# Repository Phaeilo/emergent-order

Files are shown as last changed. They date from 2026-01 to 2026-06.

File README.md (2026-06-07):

# /dev/emergent_order

An experiment in chaos and structure, presented at 39c3 (39th Chaos Communication Congress).

A 1×1×1m LED cube art installation filled with 1200 individually addressable WS2812B LEDs, creating a volumetric 3D display.

Assembled LED cube

## Overview

This repository contains most materials involved in creating the LED cube installation: software, firmware, animations, 3D mechanical parts, PCB designs, calibration tools, and documentation. The aim is to document the complete structure of the cube and make relevant tools and designs available to others who want to build their own version, learn from the project, create derivative works, or apply these concepts in entirely new ways.

## Project Structure

This repository contains the following subdirectories:

**Note:** Some directories mentioned below may not yet be available in the repository. We are actively uploading the remaining materials and expect to have everything published within the next few days.

### Hardware & Electronics

- **`controller_pcb/`** - KiCad project for a high-performance 8-channel WS2812 controller based on the Raspberry Pi Pico. Features include USB streaming mode, standalone operation with built-in test patterns, SD card playback, comprehensive monitoring (voltage, current, temperature), and per-channel smart fuse protection (3.7A). Supports up to 200 LEDs per channel at 60Hz. See [controller_pcb/README.md](controller_pcb/README.md) for complete specifications.

- **`pico_firmware/`** - C firmware for the Raspberry Pi Pico that drives 8 independent WS2812B channels via PIO hardware. Features gamma correction, automatic current limiting, hardware monitoring (temperature, current, voltage), channel fault detection, and built-in test patterns including a ternary-encoded calibration pattern for camera-based position recovery. See [pico_firmware/README.md](pico_firmware/README.md) for protocol specification and development setup.

- **`mechanical/`** - 3D printable parts (base, corners, combs, controller mounts) and carbon fiber tube specifications for building the physical cube structure. See [mechanical/README.md](mechanical/README.md) for details.

### Software & Control

- **`showrunner/`** - Node.js service that plays LED animations on the cube, streaming frames at 30-60 FPS over serial to the Pico firmware. Supports hot-swappable animations and WebSocket interface for live streaming. See [showrunner/README.md](showrunner/README.md) for details.

- **`animations/`** - JavaScript animation scripts that generate LED patterns using 3D math (SDF primitives, planes, spheres, fire effects, etc.). See [animations/README.md](animations/README.md) for examples and animation format.

- **`animation_designer/`** - Web-based tool for designing and previewing animations before deploying them to the cube. See [animation_designer/README.md](animation_designer/README.md) for usage instructions.

### Calibration & Utilities

- **`calibration/`** - Tools for recovering 3D LED positions from video captures of the cube. Includes video frame extraction, LED detection with ternary color-coded identification, and multi-camera 3D triangulation with bundle adjustment. Features both Python CLI tools and a web-based detector with real-time visualization. See [calibration/README.md](calibration/README.md) for complete workflow and encoding scheme documentation.

- **`ws2serial/`** - Python utility for testing and interfacing with WS2812 LED strips over USB serial during development. Provides a WebSocket-to-serial adapter allowing the animation designer web tool to stream pixel data over the network to the Pico controller. See [ws2serial/README.md](ws2serial/README.md) for details.

- **`testdevice/`** - MicroPython code for ESP32-C3 to quickly test single LED strings during installation and teardown. See [testdevice/README.md](testdevice/README.md) for details.

### Prototypes

- **`minikube/`** - Smaller ~20×20×20cm prototype cube with MicroPython firmware and mechanical designs for ESP32-C3. Also includes a dodecahedron variant that reuses the same stick parts. See [minikube/README.md](minikube/README.md) for details.

## Technical Specifications

- **Physical size:** 1×1×1 meter cube
- **LEDs:** 1200 individually addressable WS2812B LEDs
- **Structure:** Carbon fiber tubes (20×18mm) with 3D printed corner connectors
- **Controller:** Raspberry Pi Pico-based 8-channel controller (can be driven by Raspberry Pi 3 or run standalone)
- **Power:** Custom 4-layer PCB with 8-channel power distribution, smart fuse protection (3.7A per channel), and comprehensive monitoring
- **Software:** Node.js showrunner + JavaScript animation framework (USB streaming), or standalone test patterns
- **Communication:** USB serial (Pi 3 → Pico), PIO-based WS2812B output, WebSocket interface for live animation streaming

## Development Approach

Most of the code in this project was synthesized ("vibe coded") using various Anthropic Claude models. The goal was to rapidly prototype and get something working, so the code may not be well understood in all places or may contain bugs. However, key decisions about architecture, algorithms and artistic content were provided by humans, just not manually implemented line-by-line.

## Related Works

Others have explored similar concepts in volumetric LED displays and spatial calibration:

- **Matt Parker's Christmas Tree (2020):** Matt Parker from the YouTube channel "Stand-up Maths" set up his Christmas tree with 500 LED lights in December 2020 and calculated their positions in 3D space. His well-made and educational video documenting the process: [I wired my tree with 500 LED lights and calculated their 3D coordinates.](https://www.youtube.com/watch?v=TvlpIojusBE)

- **Birk Schmithuesen's SpeculativeAI Series (2019-2022):** Artist Birk Schmithuesen created a sphere installation filled with 160 meters of LED strips comprising 9600 pixels. Through calibration work by Felix Bonowski, volumetric content was rendered on this sphere. The project is extensively documented at [birkschmithuesen.com/_speculativeAI](https://www.birkschmithuesen.com/_speculativeAI)

## License

See the license files in individual directories or license text in source files.

In general:
- **Code/Software:** MIT License
- **3D Models:** CC-BY 4.0
- **PCB Designs:** CERN-OHL-W (CERN Open Hardware License - Weakly Reciprocal)

## Contributing

This project was created for 39c3. Feel free to fork, modify, and create your own versions. If you build something based on this work, we'd love to hear about it!

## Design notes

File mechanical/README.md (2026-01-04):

# Mechanical Parts for LED Cube

This directory contains all the 3D models and specifications for building the physical structure of the 1×1×1m LED cube.

## Overview

The cube structure consists of:
- **Carbon fiber tubes** forming the main frame (12 edges of the cube)
- **3D printed connectors** to join the tubes at corners and base
- **3D printed cable management** combs to route LED wires
- **MDF base** housing all electronics
- **Controller mounting hardware**

## Bill of Materials

### Structural Components

#### Carbon Fiber Tubes

Ordered from "CARBON TIME" store on AliExpress:
- **Store:** [CARBON TIME](https://de.aliexpress.com/store/911756291)
- **Product:** [20mm Carbon Fiber Tubes](https://de.aliexpress.com/item/1005002337416341.html)

**Quantities needed:**
- 9× tubes 20×18×1000mm (outer × inner × length)
- 3× tubes 20×16×1000mm (for bottom connections to base)
  - Note: 20×18mm can be used for everything if you prefer consistency

**Finish:** Twill matte

#### LED Strings

**Product:** WS2812B addressable LED string ([AliExpress link](https://de.aliexpress.com/item/1005001915144430.html))

**Specifications:**
- 20m string with 10 LEDs per meter (200 LEDs total per string)
- 6 strings required for the installation

**Total LEDs:** 1200 LEDs (200 LEDs × 6 strings)

**Important Notes:**
- 20m strings are pushing the limit when only injecting power from one end
- Software current limiting is required to avoid incorrect colors at the far end of the string
- This is a trade-off between fewer string connections and power distribution challenges
- Wire appearance: would look better if wire were painted black, but such a product doesn't exist off-the-shelf
- Wire stretching: the wire will stretch during/after installation, and especially with temperature gradients in long-term installations. Consider a re-tensioning concept or better securing method for permanent installations

#### MDF Base

The base houses all electronics and provides structural support:

- **Construction:** Two pieces of 40×40cm MDF + battens screwed together
- **Finish:** Painted black
- **Features:**
  - Houses Raspberry Pi 4, controller PCB, power supply
  - Covered by PLA honeycomb grills for visual cover and ventilation
  - 2× Noctua 40×40mm fans in the back for airflow
  - Cable access holes

### 3D Printed Parts

All 3D model files (.3mf format) are included in this directory. CAD source files are available on Onshape (links below).

#### Base Corner Connector

**File:** `base.3mf`

**Onshape CAD:** [View on Onshape](https://cad.onshape.com/documents/e40c83297a2b759d68be7f6e/w/c118c41bf27f27ad78296554/e/638a71450e9c66e4a3123774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)

**Quantity:** 1

**Purpose:** Holds three carbon fiber pipes at the bottom of the cube and secures them to the MDF base plate.

**Features:**
- Secured to base with 4× M5 screws
- Cable routing hole for LED wires

**Print Settings:**
- Material: PETG (recommended for strength)
- Layer height: 0.2mm
- Perimeter walls: 4+ for strength

**Assembly Notes:**
- This is a high-stress part - the 1m CF tubes create significant leverage
- While PETG prints work, aluminum parts would be more durable for permanent installations
- Handle the cube carefully to avoid breaking this part
- Print spare/replacement parts

---

#### Corner Connector

**File:** `corner.3mf`

**Onshape CAD:** [View on Onshape](https://cad.onshape.com/documents/e40c83297a2b759d68be7f6e/w/c118c41bf27f27ad78296554/e/c4481eaa0fdde92928e6f618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)

**Quantity:** 7 (one for each corner of the cube, except base)

**Purpose:** Connects 3 carbon fiber pipes at 90° angles to form cube corners.

**Print Settings:**
- Material: PETG
- Layer height: 0.2mm
- Shells/perimeters: 4+
- Orientation: Place on corner point for symmetric print

**Assembly Notes:**
- Friction fit design: pipes press into the connector
- Tolerances may vary: be prepared to file, sand, or heat-form for proper fit
- If fit is too loose: wrap electrical tape around CF tube end before inserting
- For permanent installations: consider adding set screws to secure tubes
- Not verified for prolonged thermal cycling (sun, seasons, etc.)

---

#### Cable Management Comb

**File:** `comb.3mf`

**Onshape CAD:** [View on Onshape](https://cad.onshape.com/documents/e40c83297a2b759d68be7f6e/w/c118c41bf27f27ad78296554/e/f5acbb86f4773182431e6e56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)

**Quantity:** 60 total (5 per 1m CF pipe × 12 pipes)

**Purpose:** Guides and organizes LED string wires along the carbon fiber tubes.

**Attachment:** Zip ties

**Print Settings:**
- Material: PLA (no significant structural load)
- Layer height: 0.2mm

**Assembly Notes:**
- Attach with small zip ties to CF tubes
- Route LED wires through the comb teeth

---

#### Controller PCB Mount

**File:** `controller_mount.3mf` and `controller_clamp.3mf`

**Onshape CAD:** [View on Onshape](https://cad.onshape.com/documents/70f768b329ba066f39a94f12/w/328bc72038fa8f24f8fcde96/e/15a5e0a3f1c87c68c4469b0a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)

**Quantity:** 1

**Purpose:** Provides solid base for the controller PCB and strain relief for LED cables.

**Features:**
- Screw mounting points for PCB (M3 threaded inserts required)
- Cable clamps for LED string wire management

**Print Settings:**
- Material: PLA or PETG
- Draft settings acceptable (fast print)
- May not need top/bottom solid layers (just perimeters)

**Assembly Notes:**
- Install M3 threaded inserts (heat-set recommended)
- Secure PCB with M3 screws
- Route LED cables through clamps before connecting to PCB

## License

3D models are licensed under [CC-BY 4.0](https://creativecommons.org/licenses/by/4.0/)

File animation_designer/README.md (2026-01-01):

# LED Cube Animation Designer

A web-based tool for creating, testing, and live-streaming animations to the LED cube.
It was used to prepare content for the installation, but also used during the installation to 
stream "live" content to the cube.

## Features

### Visual Editor
- **3D Preview**: Real-time visualization of your animations in an interactive 3D viewport
- **Parameter Controls**: Auto-generated UI controls for all animation parameters
- **Preset Management**: Save and load your favorite parameter configurations

### Code Editor
- Live JavaScript editor with error display
- Same format as the [animations/](../animations/) directory scripts
- Supports full parameter system with types, ranges, and grouping

### Live Streaming
- **WLED Integration**: Connect directly to WLED devices via WebSocket
- **Dual Protocols**: Support for WLED JSON and binary protocols
- **Adjustable FPS**: Stream at 20-120 FPS
- **Coordinate Import**: Load actual LED positions for accurate preview

### Distribution Modes
- **Grid**: Regular 3D grid distribution
- **Random**: Random point cloud
- **Import**: Use actual LED coordinates from the physical cube

## Getting Started

### Local Use

1. Open `index.html` in a web browser
2. Write your animation code in the editor (or load an existing script)
3. Click **Run** (or press `Ctrl+Enter`) to start the animation
4. Adjust parameters in real-time using the generated controls

### Connecting to Hardware

1. Enter your WLED device IP address (e.g., `192.168.1.100`)
2. Select protocol and FPS
3. Click **Connect**
4. Run your animation - it will stream to the physical cube!

## Animation Format

See the [animations README](../animations/README.md) for the script format. Quick overview:

```javascript
const params = {
    myGroup: {
        group: 'My Parameters',
        speed: { type: 'float', name: 'Speed', min: 0.0, max: 5.0, default: 1.0 },
        color: { type: 'color', name: 'Color', default: [1.0, 0.0, 0.0] }
    }
};

function getSphereColor(x, y, z, t, params, id) {
    // x, y, z: LED position (0.0 to 1.0)
    // t: time in seconds
    // params: your parameter values
    // id: LED index
    // Return: [r, g, b] color (0.0 to 1.0)

    return [1.0, 0.0, 0.0]; // Your logic here!
}
```

## Tips

- Use `Ctrl+Enter` to run, `Ctrl+.` to stop
- Start with simple effects and build complexity gradually
- Check the console for JavaScript errors
- Use the default script (`default_script.js`) as a reference
- Parameter changes apply immediately - no need to restart

## Files

- `index.html` - Main application page
- `script.js` - Application logic and 3D rendering
- `style.css` - UI styling
- `default_script.js` - Example animation
- `convert_coords.py` - Utility for converting LED coordinate formats

## License

Designer tool is licensed under MIT

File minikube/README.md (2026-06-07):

# Minikube - LED Cube Prototype

A smaller ~20×20×20cm prototype version of the main 1m LED cube, perfect for testing animations and learning the concepts without building the full installation.

## Overview

The minikube is a fully self-contained LED cube made entirely from 3D printed parts, M3 screws, a single WS2812B LED strand, and a MicroPython-compatible microcontroller. It runs standalone without requiring a Raspberry Pi or custom PCB, making it an excellent starting point for experimentation.

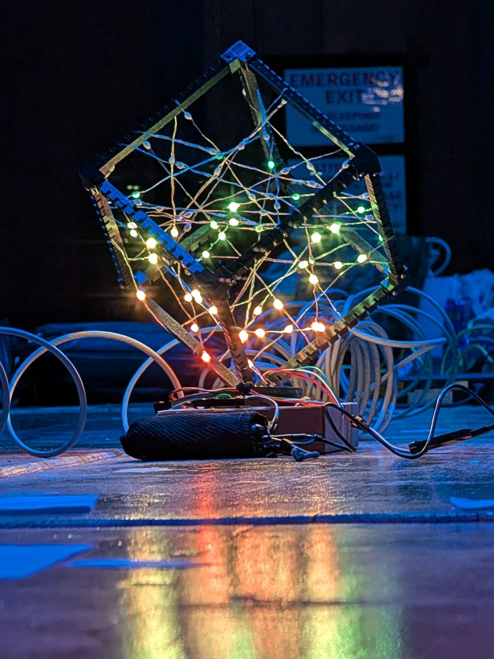
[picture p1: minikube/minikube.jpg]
Assembled minikube LED cube


## Features

- **Standalone operation:** Runs animations directly on ESP32-C3 with MicroPython
- **Fully 3D printed:** No carbon fiber tubes or specialized parts needed
- **Low cost:** Uses readily available components
- **Self-contained:** All animation code runs on the microcontroller
- **Easy to build:** Simpler assembly than the main cube
- **Portable:** Small size makes it easy to transport and demo

## Bill of Materials

### Electronics

- **Microcontroller:** ESP32-C3 development board ([AliExpress link](https://de.aliexpress.com/item/1005007205044247.html))
  - Any ESP32 variant that supports MicroPython and WS2812 control will work
  - Recommended: 4MB flash or more

- **LED Strip:** WS2812B addressable LED string ([AliExpress link](https://de.aliexpress.com/item/1005001915144430.html))
  - 10m string with 10 LEDs per meter (100 LEDs in total) is sufficient

- **Power Supply:** Any USB supply to power the ESP and LED string

- **Optional:** 3.3V to 5V level shifter for data line
  - A small PCB with 4× WS2812 LEDs works well for this purpose ([AliExpress link](https://de.aliexpress.com/item/1005010216258357.html))
  - Not strictly necessary but improves signal integrity

### Mechanical

- **M3 screws:** 24× M3 screws, approximately 8mm length
- **3D printed parts:** See [mechanical/README.md](mechanical/README.md)
  - 12× Stick parts
  - 7× Corner parts
  - 1× Base part

### Tools

- 3D printer with PLA or PETG filament
- Soldering iron and solder
- Wire strippers
- Screwdriver
- Electrical tape or zip-ties
- Computer with USB for programming

## Project Structure

- **`firmware/`** - MicroPython code that runs on the ESP32-C3. See [firmware/README.md](firmware/README.md) for installation instructions, wiring, usage, and animation development.

- **`mechanical/`** - 3D printable parts and assembly instructions. See [mechanical/README.md](mechanical/README.md) for part specifications, printing guidelines, and assembly steps.

## Getting Started

1. **Build the physical cube:** Follow the instructions in [mechanical/README.md](mechanical/README.md) to print parts and assemble the structure.

2. **Install firmware and wire electronics:** Follow the instructions in [firmware/README.md](firmware/README.md) to flash MicroPython, wire the electronics, and upload the firmware.

3. **Calibrate LED positions:** Use the calibration tools in `../calibration/` to map the 3D coordinates of each LED for accurate volumetric rendering.

## Variants

### Dodecahedron

A dodecahedral variant uses the same **stick** parts as the cube, combined with a
different corner piece. It needs no base.

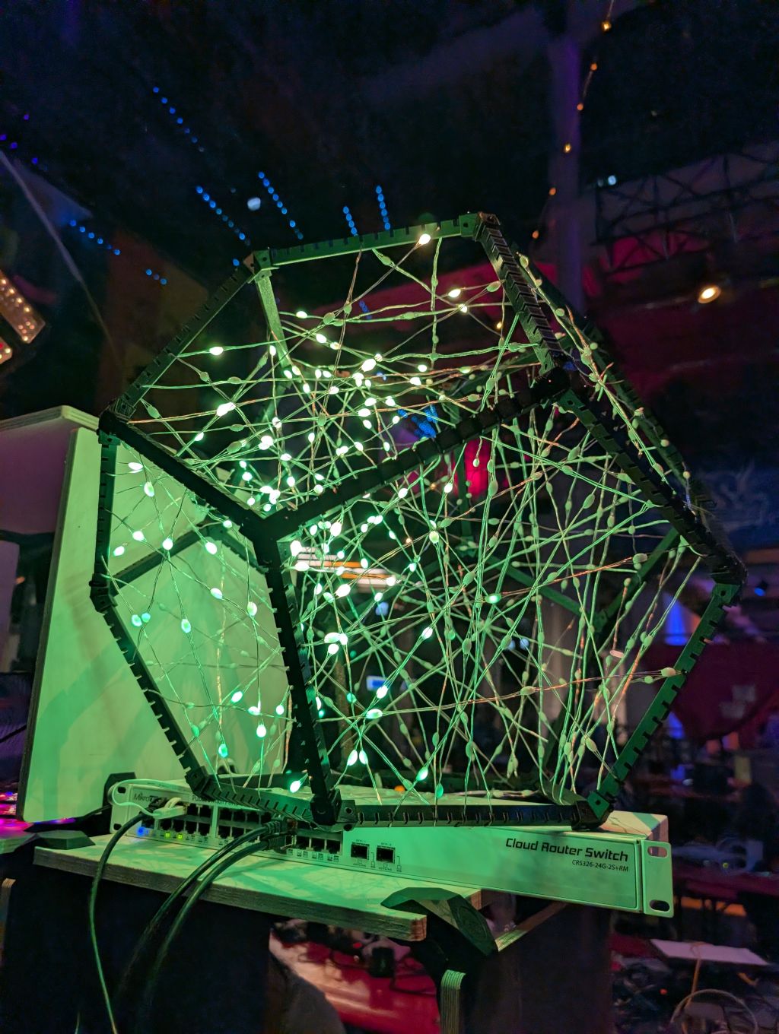
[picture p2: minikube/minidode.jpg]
Assembled dodecahedron variant


- **Sticks:** 30× (same part as the cube)
- **Corners:** 20× dodecahedron corner pieces ([mechanical/corner_dodecahedron.3mf](mechanical/corner_dodecahedron.3mf))
- **Base:** Not needed
- **LEDs:** Pictured with 2 strings of 200 LEDs each (400 LEDs total)
- **M3 screws:** 60× (2 per stick)

Assembly follows the same approach as the cube: connect sticks to corners with M3
screws to form the frame, then thread the LED strings through the volume.

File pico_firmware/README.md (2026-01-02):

# Pico Firmware - WS2812 Proxy

Multi-channel USB-to-WS2812 bridge. Receives RGB pixel data via USB serial and drives 8 independent WS2812 LED channels with hardware acceleration.

## Features

- **8 independent WS2812 channels** (GPIO 8-15) via PIO hardware
- **Up to 200 LEDs per channel** @ 60Hz refresh rate
- **Gamma correction** (γ=2.8, configurable)
- **Automatic current limiting** with per-channel brightness scaling
- **Hardware monitoring**: 2x NTC temperature sensors, INA226 current/voltage monitor
- **Channel fault detection**: 8x voltage feedback channels with trip detection
- **Built-in test patterns** (6 patterns, auto-activation after 5s timeout)
- **USB CDC serial** for high-speed data transfer (512-byte buffers)
- **Periodic status reports** (1Hz over serial)

## Serial Protocol

### Upstream (Host → Pico): LED Data Commands

All multi-byte values are little-endian.

| Command | Format | Description |
|---|---|---|
| `0xFF` | `[0xFF][CH][CNT_L][CNT_H][RGB...]` | Update channel and flush immediately |
| `0xFE` | `[0xFE][CH][CNT_L][CNT_H][RGB...]` | Update channel buffer only (no flush) |
| `0xFD` | `[0xFD][MASK]` | Flush selected channels (8-bit mask) |
| `0xFC` | `[0xFC]` | Reset Pico |
| `0xFB` | `[0xFB][PATTERN_ID]` | Start test pattern (0-5) |
| `0xFA` | `[0xFA]` | Stop test pattern |
| `0xF9` | `[0xF9]` | Clear all LEDs (black + flush) |

- `CH`: Channel ID (0-7)
- `CNT_L/CNT_H`: LED count (16-bit, little-endian)
- `RGB...`: RGB triplets (R, G, B bytes per LED)
- `MASK`: Channel mask (bit 0=ch0, bit 1=ch1, etc.)

### Downstream (Pico → Host): Status Messages

Status reports sent every 1 second:

```
STATS up=<uptime> cmd=<commands> pix=<pixels> flush=<flushes> err=<errors> t0=<temp0> t1=<temp1> v=<voltage> i=<current> fb=<fb_mask> trip=<trips> lim=<limits> mode=<mode>
```

**Fields:**
- `up`: Uptime (seconds)
- `cmd`: Total commands received
- `pix`: Total pixels processed
- `flush`: Total flush operations
- `err`: Error count
- `t0/t1`: Temperature (°C) from NTC sensors
- `v`: Bus voltage (V)
- `i`: Current draw (A)
- `fb`: Feedback mask (0xFF=all channels OK, bit cleared=channel tripped)
- `trip`: Total channel trip events
- `lim`: Total current limit events
- `mode`: System mode (0=normal, 1=test pattern)

**Fault notifications:**
```
Channel <ch> TRIPPED! (voltage: <v>V, threshold: <thresh>V)
Channel <ch> recovered (voltage: <v>V)
```

## Development Environment Setup

### Prerequisites

Install ARM GCC toolchain and CMake.

### Initialize Submodules

```bash
cd pico_firmware
git submodule update --init --recursive
```

This initializes:
- `pico-sdk/` - Raspberry Pi Pico SDK
- `picotool/` - Upload utility

### Build

```bash
./build.sh              # Incremental build
./build.sh --clean      # Clean build
```

Output: `build/wsproxy.uf2`

### Upload to Pico

**Method 1: USB bootloader (drag-and-drop)**
1. Hold BOOTSEL button while plugging in Pico
2. Copy `build/wsproxy.uf2` to the mounted drive

**Method 2: picotool (requires picotool installed)**

```bash
./build.sh --upload     # Build and upload via picotool
```

Or manually:
```bash
picotool load -f -x build/wsproxy.uf2
```

## Python Client (`ws_ctrl.py`)

CLI tool for controlling the WS2812 proxy. Can also be imported as a library (see source for API).

### Usage

```bash
# Test patterns
./ws_ctrl.py -p /dev/ttyACM0 pattern --start 0
./ws_ctrl.py -p /dev/ttyACM0 pattern --stop

# Set all LEDs to a color
./ws_ctrl.py -p /dev/ttyACM0 color 255 0 0           # Red, all channels
./ws_ctrl.py -p /dev/ttyACM0 color 0 255 0 -c 0,1,2  # Green, channels 0-2

# Clear and reset
./ws_ctrl.py -p /dev/ttyACM0 clear
./ws_ctrl.py -p /dev/ttyACM0 reset
```

## Hardware Configuration

### WS2812 Outputs (8 channels)
- GPIO 8-15 → CTRL_0 to CTRL_7 (WS2812 strings 0-7)

### User Interface
- GPIO 2 → LED_0 (primary status LED)
- GPIO 3 → LED_1 (secondary status LED)
- GPIO 6 → BTN_0 (primary button, active low)
- GPIO 7 → BTN_1 (secondary button, active low)

### Monitoring & Sensors
- GPIO 26 (ADC0) → NTC_0 (primary temperature sensor)
- GPIO 27 (ADC1) → NTC_1 (secondary temperature sensor)
- GPIO 28 (ADC2) → FB_M (feedback multiplexer output)
- GPIO 20-22 → FB_S0, FB_S1, FB_S2 (feedback multiplexer address)

### I2C Bus
- GPIO 4 → SDA (INA226 current sensor + optional display header)
- GPIO 5 → SCL

### SD Card (SPI)
- GPIO 16 → SD_DO
- GPIO 17 → SD_CS
- GPIO 18 → SD_CLK
- GPIO 19 → SD_DI

### UART
- GPIO 0 → UART0_TX
- GPIO 1 → UART0_RX

## License

MIT License

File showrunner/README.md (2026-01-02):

# Showrunner

Node.js service that plays LED animations on the cube, streaming frames at 30-60 FPS over serial to the Raspberry Pi Pico firmware.

**Features:**
- Loads LED coordinates from calibration files
- Executes animation JavaScript
- Binary serial protocol compatible with Pico firmware
- Hot-swappable animations at runtime
- WebSocket server for live animation streaming (interrupts scheduled content)
- Status file with health data from service and Pico (for external monitoring)

## Installation

```bash
npm install
```

## Configuration

Configure via environment variables (see `.env.example` for all options):

**Required:**
- `LED_COORDS_FILE` - Path to LED coordinate calibration file
- `ANIMATION_DIR` - Directory containing animation JavaScript files

**Optional:**
- `INITIAL_ANIMATION` - Starting animation filename (default: `simple_sphere_script.js`)
- `FPS` - Target frame rate (default: `30`)
- `SERIAL_PORT_BASE` - Serial port base path (default: `/dev/ttyACM`)
- `ANIMATION_CONTROL_FILE` - File to watch for animation switching (default: `/var/run/led_animation`)
- `STATUS_FILE` - Status/health data output file (default: `/var/run/led_status.json`)
- `WS_LISTEN` - WebSocket server listen address (default: `127.0.0.1:8080`)
- `LOG_LEVEL` - Logging level: debug, info, warn, error (default: `info`)

## Running

```bash
npm start
```

To switch animations at runtime, write the animation filename to the control file:

```bash
echo "simple_sphere_script.js" > /var/run/led_animation
```

## License

MIT License

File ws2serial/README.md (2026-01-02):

# WS2Serial

A WebSocket-to-serial bridge for development and testing of LED animations. During development, the animation_designer web app needs to send animation data to the Raspberry Pi Pico (which drives the LED strips). Since the animation designer runs in a browser and uses WebSockets, this component provides a server that accepts WebSocket connections and forwards the data to the serial port connected to the Pico.

## Features

- **WebSocket server** - Accepts connections on port 8080 (configurable)
- **Serial bridge** - Bidirectional data flow between WebSocket and USB serial port
- **Connection management** - Single active connection with optional force-takeover support
- **Real-time statistics** - Reports message/byte rates for both directions every 3 seconds

## Usage

```bash
python main.py --serial /dev/ttyACM0 [--host 0.0.0.0] [--port 8080]
```

Connect via WebSocket at `ws://hostname:8080/ws` (add `?force=1` to take over existing connection).

## License

MIT License

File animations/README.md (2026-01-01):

# LED Cube Animations

This directory contains animation scripts that were run on the LED cube during the installation at **39c3**. These serve as examples and inspiration for creating your own volumetric effects. Feel free to toy around with the parameters, modify existing animations, or create entirely new ones!

## Format

Each animation script exports:

- `params` - Configuration parameters organized into groups with types, ranges, and defaults
- `getSphereColor(x, y, z, t, params, id)` - Main rendering function that returns RGB color `[r, g, b]` for each LED

### Function Parameters

- `x, y, z` - LED position in normalized coordinates (0.0 to 1.0)
- `t` - Time in seconds since animation start
- `params` - User-configurable parameters
- `id` - LED index in the string

## Available Animations

### Basic Effects
- `blink_red.js` / `blink_green.js` / `blink_blue.js` - Simple color blinking with configurable count and speed

### 3D Effects
- `simple_fire_script.js` - Volumetric fire effect with Perlin noise turbulence
- `simple_sphere_script.js` - Distorted sphere with color gradients
- `simple_plane_script.js` - Monochromatic rotating plane that fades into and out of chaos
- `simple_cylinder_ring_script.js` - Colorful cylinders that rotate and also dissolbe into chaos
- `simple_chase_script.js` - Linear chase patterns with volumetric color

## Getting Started

Load these scripts into the animation designer and play around with parameters.
Alternatively, deploy them via the showrunner service.

## License

Animations are licensed under MIT

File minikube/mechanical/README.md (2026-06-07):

# Minikube Mechanical Parts

These are the mechanical parts for the "minikube" LED cube. All parts are fully 3D printable.

## Parts List

### Stick
- **Quantity:** 12
- **Onshape CAD:** [View model](https://cad.onshape.com/documents/35b631ccccc90ff975992415/w/c20a5f2e54700722651818f8/e/14eca066540b0de742dcb656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)

### Corner
- **Quantity:** 7
- **Onshape CAD:** [View model](https://cad.onshape.com/documents/35b631ccccc90ff975992415/w/c20a5f2e54700722651818f8/e/af9102617ac8ab6626cb2768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)

### Base
- **Quantity:** 1
- **Onshape CAD:** [View model](https://cad.onshape.com/documents/35b631ccccc90ff975992415/w/c20a5f2e54700722651818f8/e/fb26ce946a9d956585137d0c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)

### Corner (Dodecahedron variant)
- **Quantity:** 20
- **File:** [corner_dodecahedron.3mf](corner_dodecahedron.3mf)
- **Onshape CAD:** [View model](https://cad.onshape.com/documents/35b631ccccc90ff975992415/w/c20a5f2e54700722651818f8/e/26bb227b4a6fb8bb9e3b2848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)
- Used for the dodecahedron variant together with 30× Stick parts & 60 M3 screws. No base needed.

## Hardware Required

- **M3 screws:** 24× screws, approximately 8mm length
  - Used to securely connect sticks with corners

## Printing Guidelines

- **Material:** PLA or PETG recommended
- **Layer height:** 0.2mm
- **Settings:** Standard settings should work fine

## Assembly Instructions

1. **Print all parts:**
   - 12× Stick
   - 7× Corner
   - 1× Base

2. **Assemble the cube frame:**
   - Connect sticks to corners using M3 screws to form the cube structure
   - Secure the base to the bottom of the cube frame

4. **Thread the LED string:**
   - Start at the base: secure the start of the string with a loop, or zip-tie
   - Thread the string using a chaotic pattern to fill the volume
   - Secure the end of the strip

## License

3D models are licensed under [CC-BY 4.0](https://creativecommons.org/licenses/by/4.0/)

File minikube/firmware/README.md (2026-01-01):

# Minikube Firmware

MicroPython firmware to drive the LEDs of the minikube (single WS2812 string) with an ESP32-C3. Different ESP models or other microcontrollers may also work, provided they are capable of running MicroPython and driving a WS2812 string.

## Wiring Electronics

1. **Connect LED strip:**
   - Either solder strip directly to ESP32 pads, or use a connector
   - LED strip 5V to ESP32 VBUS
   - LED strip GND to ESP32 GND
   - LED data input to ESP32 pin 20 (configurable in `config.py`)

2. **Optional level shifter:**
   - Insert 3.3V to 5V level shifter between ESP32 and LED data line
   - A small PCB with 4× WS2812 LEDs works well for this purpose ([AliExpress link](https://de.aliexpress.com/item/1005010216258357.html))
   - Not strictly necessary but improves signal integrity

4. **Power the ESP32:**
   - Connect ESP32 via USB

## Installation Instructions

### 1. Flash MicroPython

Download MicroPython firmware for ESP32-C3 from [micropython.org](https://micropython.org/download/ESP32_GENERIC_C3/) and flash it using esptool.

### 2. Configure Settings

Edit `config.py` to configure:
- GPIO pin numbers
- Number of LEDs
- Other hardware-specific settings (see comments in file)

### 3. Upload Firmware

Upload all files from this directory to the ESP32 using [mpremote](https://docs.micropython.org/en/latest/reference/mpremote.html):

```bash
mpremote connect /dev/ttyACM0 cp -r * :
```

### 4. Verify Operation

Monitor serial output to ensure everything runs correctly:

```bash
mpremote connect /dev/ttyACM0
```

### 5. Calibrate LED Positions

For the animations to look correct, the exact 3D position of each LED must be known:

1. Press the boot button on the ESP32 to cycle animations and bring up the calibration pattern (TODO: not yet implemented in firmware)
2. Capture calibration images/videos of the cube from different perspectives
3. Process the data and generate a LED calibration text file using the tools in `../../calibration/`
4. Upload the LED calibration results (positions) as `solution1.txt` to the ESP32:
   ```bash
   mpremote connect /dev/ttyACM0 cp solution1.txt :
   ```

After calibration, the volumetric animations will render correctly!

## Usage

- **Cycle animations:** Press the boot button of the ESP32
- **Modify animations:** Edit Python files in `animations/`
- **Create new animations:** Subclass `AnimationBase` and implement the `render()` method
- **Adjust speed/colors:** Modify parameters in the animation files

## Animation Framework

The firmware includes a simple animation framework:

- **`animation_base.py`** Base class for animations
- **`sdf_primitives.py`** Signed distance field primitives for 3D shapes
- **`math_utils.py`** Vector math, noise functions
- **`color_utils.py`** Color manipulation and conversion
- **`coordinate_loader.py`** Loads LED positions from calibration file

Example animations included:
- **`plane_animation.py`** Animated plane sweeping through the cube
- **`sphere_animation.py`** Pulsing sphere effect

## License

Firmware is licensed under MIT

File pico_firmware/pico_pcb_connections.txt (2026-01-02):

# PICO_PIN  PCB_PIN     (comment)

# WS2812 outputs
GPIO_8  CTRL_0  (WS2812 string 0)
GPIO_9  CTRL_1  (WS2812 string 1)
GPIO_10 CTRL_2  (WS2812 string 2)
GPIO_11 CTRL_3  (WS2812 string 3)
GPIO_12 CTRL_4  (WS2812 string 4)
GPIO_13 CTRL_5  (WS2812 string 5)
GPIO_14 CTRL_6  (WS2812 string 6)
GPIO_15 CTRL_7  (WS2812 string 7)

# user interface
GPIO_2  LED_0   (primary onboard status LED)
GPIO_3  LED_1   (secondary onboard status LED)
GPIO_6  BTN_0   (primary button, external pull-up, low if pushed)
GPIO_7  BTN_1   (secondary button, external pull-up, low if pushed)

# thermal
GPIO_26_ADC0    NTC_0   (primary thermal sensor)
GPIO_27_ADC1    NTC_1   (secondary thermal sensor)
INA226
# voltage feedback
GPIO_28_ADC2    FB_M    (output from feedback multiplexer)
GPIO_20         FB_S0   (address S0 to feedback multiplexer)
GPIO_21         FB_S1   (address S1 to feedback multiplexer)
GPIO_22         FB_S2   (address S2 to feedback multiplexer)

# SD Card slot
GPIO_16     SD_DO
GPIO_17     SD_CS
GPIO_18     SD_CLK
GPIO_19     SD_DI

# I2C
GPIO_4  SDA     (connected to INA226 for current sensing, bus also has header where user may attach display (SSH 1106))
GPIO_5  SCL

# UART
GPIO_0  UART0_TX
GPIO_1  UART0_RX

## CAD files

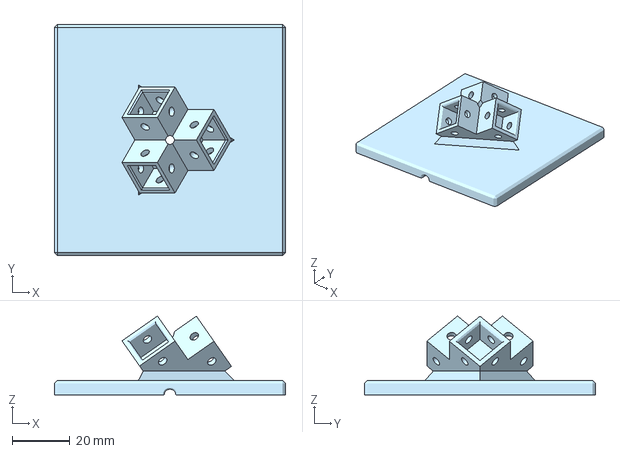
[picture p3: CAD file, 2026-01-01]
minikube/mechanical/base.3mf
80.0 x 80.0 x 27.4 mm

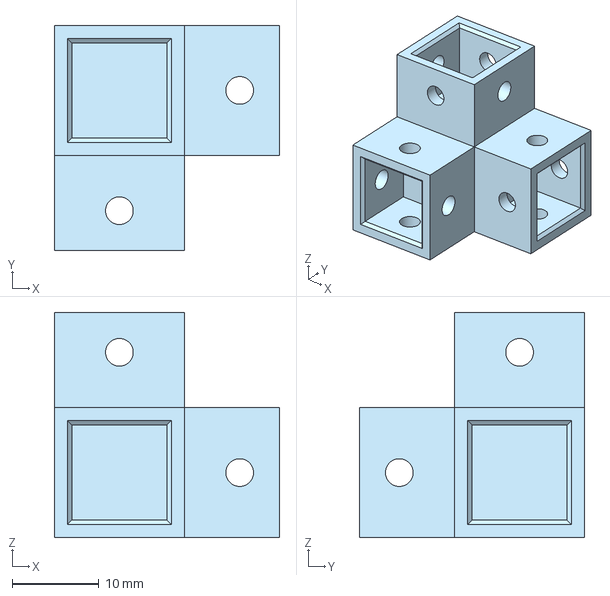
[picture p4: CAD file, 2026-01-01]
minikube/mechanical/corner.3mf
26.0 x 26.0 x 26.0 mm

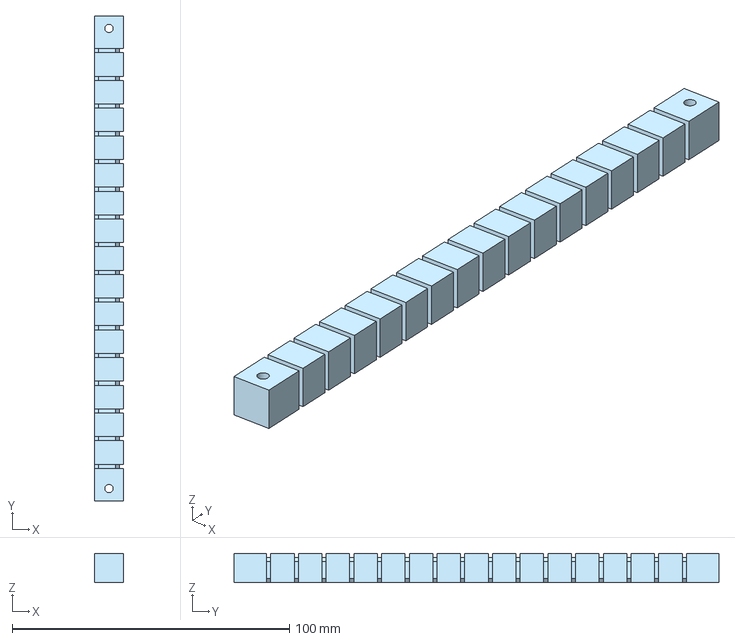
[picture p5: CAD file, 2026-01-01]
minikube/mechanical/stick.3mf
10.6 x 175.0 x 10.6 mm

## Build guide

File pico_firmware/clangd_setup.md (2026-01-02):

# clangd Setup for Pico SDK

## Steps to configure clangd:

1. Generate compilation database:
   ```bash
   cmake -S . -B build -DCMAKE_EXPORT_COMPILE_COMMANDS=ON
   ```

2. Symlink to project root:
   ```bash
   ln -sf build/compile_commands.json compile_commands.json
   ```

3. Create `.clangd` config file with ARM target flags

4. Restart LSP/editor

## Files created:
- `compile_commands.json` (symlink)
- `.clangd` (config for ARM cross-compilation)

## Maintenance:
- `compile_commands.json` auto-regenerates on each cmake configure
- Restart LSP after regenerating build files

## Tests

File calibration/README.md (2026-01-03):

# Cube Calibration Utils

Tools for recovering 3D LED positions from the chaotic LED cube installation.

## Overview

This calibration system uses a ternary color-coded identification scheme where LEDs flash specific color sequences that encode their unique IDs. Multiple camera perspectives capture these sequences, and the 2D detections are triangulated to recover 3D positions.

## Tools

### frame_extractor.py
Automated video processing tool that extracts calibration frames from video recordings.

**What it does:**
- Analyzes video frame-by-frame to detect brightness changes
- Identifies calibration sequences by detecting magenta color markers
- Extracts frames between magenta markers (configurable sequence length, default: 9 frames)
- Extracts corresponding dark frames for background subtraction
- Saves extracted frames as PNG files with structured naming

**Usage:**
```bash
uv run frame_extractor.py video.mp4
```

**Output:** PNG files named `{video_name}_subseq_{N}_{frame_number}.png` and `{video_name}_subseq_{N}_{frame_number}_dark.png`

### led_detector.html (+ .js + .css)
Modern web-based LED detector with real-time visual feedback.

**What it does:**
- Loads image sequences from a single camera perspective
- Performs background subtraction using dark frames
- Classifies pixel colors as Red, Green, Blue, or White
- Decodes ternary LED IDs from color sequences
- Validates LED IDs using checksum
- Computes LED centroid positions
- Exports results as text files

**Usage:**
Open `led_detector.html` in a web browser, drag and drop images (including dark frame and optional mask frame).

**Output format:**
```
FRAME_SIZE width height
LED_subseq_id x y
LED_subseq_id x y
...
```

### led_detector_sequenced.py
Command-line Python LED detector (legacy, less convenient than HTML version).

**What it does:**
Same functionality as HTML version but controlled via command-line arguments and environment variables.

**Usage:**
```bash
LOG_LEVEL=INFO DEBUG_OUTPUT=1 uv run led_detector_sequenced.py images/*.png
```

**Environment variables:**
- `LOG_LEVEL`: Logging verbosity (DEBUG, INFO, WARNING, ERROR)
- `DEBUG_OUTPUT`: Set to "1" to generate debug images

**Output:** Writes results to stdout, debug images if enabled

### rename_video.py
Simple utility for batch renaming video files (no external dependencies).

**What it does:**
Renames Google Pixel video files (format: `PXL_*.mp4`) to simple sequential names (`a.mp4`, `b.mp4`, `c.mp4`, etc.).

**Usage:**
```bash
./rename_video.py [directory]
```

If no directory is specified, operates on current directory.

### led_solver.py
3D reconstruction tool that triangulates LED positions from multiple camera perspectives.

**What it does:**
- Loads 2D LED observations from multiple cameras
- Performs camera calibration (estimates camera poses)
- Triangulates 3D LED positions using multiple views
- Applies bundle adjustment optimization
- Implements robust outlier rejection:
  - Statistical outlier detection (MAD-based)
  - RANSAC for camera pose estimation
  - Reprojection error validation
  - Iterative refinement
- Generates 3D visualization

**Usage:**
```bash
uv run led_solver.py camera1.txt camera2.txt camera3.txt --output solution.txt --viz visualization.html
```

**Optional arguments:**
- `--output`, `-o`: Output file for 3D LED positions
- `--viz`, `-v`: Generate HTML visualization
- `--top`: Comma-separated LED IDs near top (for orientation)
- `--bottom`: LED IDs near bottom
- `--left`: LED IDs near left
- `--right`: LED IDs near right

**Output format:**
```
LED_0000 -0.032561 0.357653 -0.102755
LED_0001 0.123456 -0.234567 0.345678
LED_0002 0.987654 0.654321 -0.123456
...
```
The solver may also output additional metadata and statistics as comments (lines starting with `#`).

## Full Calibration Workflow

### 1. Display Calibration Pattern
Run the calibration pattern on your LED installation. The pattern should:
- Flash magenta at the start and end of each sequence to mark boundaries
- Display 9 color frames (Red/Green/Blue) encoding LED IDs in ternary (see "LED ID Encoding Scheme" section below)
- Include dark frames (all LEDs off) between lit frames for background subtraction
- Allow enough time between color transitions for camera exposure (aim for 3-5 lit frames per color state)

### 2. Capture Videos
Record videos from multiple angles with consistent settings.

**Tested Configuration:**
- **Camera**: Google Pixel 9 Pro
- **Resolution**: 4K 60fps
- **Zoom**: 1x (no zoom)

**Critical Camera Settings:**
- **Fixed exposure** (lowest setting) - prevents LED overexposure and maintains consistency
- **Fixed color temperature** - ensures consistent color interpretation across frames
- **Fixed focus** - re-establish for each camera position, but don't change during recording
- **Ambient light** - provides context for the scene (will be removed via dark frame subtraction)
  - If LEDs are the only light source, color decoding may be unreliable

**Capture Guidelines:**
- Use a tripod for stability
- Capture at least 6+ perspectives for best results
- Vary camera angles significantly between captures
- Vary camera height - don't stay at ground level
- Ensure each camera can see a large portion of the cube (though close-up shots that capture smaller sections are also acceptable and can improve local accuracy)
- Avoid reflections in the environment, or mask them in post-processing
- Record one complete calibration sequence per perspective
- Don't move the cube or LEDs between captures

### 3. Rename and Extract Frames
```bash
# Rename video files for convenience (no dependencies, can run directly)
./rename_video.py /path/to/videos/

# Extract frames from each video
uv run frame_extractor.py a.mp4
uv run frame_extractor.py b.mp4
uv run frame_extractor.py c.mp4
# ... etc for each video
```

This produces frame files like:
```
a_subseq_01_0167_dark.png    (dark/background frame)
a_subseq_01_0179.png         (ternary digit 0)
a_subseq_01_0203.png         (ternary digit 1)
...
a_subseq_01_0324.png         (ternary digit 8)
```

### 4. Detect LED Positions
For each set of extracted frames:

1. Open `led_detector.html` in a web browser
2. Drag and drop all frames from one camera perspective (including dark frame)
3. Adjust parameters if needed:
   - **Brightness threshold**: Increase if too many false detections, decrease if missing LEDs
   - **Color purity**: Higher values require purer colors (reduces crosstalk)
   - **Green correction**: Adjust if greens appear blue/cyan
   - **Min pixels per LED**: Filter out small noise artifacts
4. Use masks to exclude reflections or unwanted regions
5. Verify detection quality using visualization modes
6. Click download button to save results
7. Save with consistent naming (e.g., `perspective_0.txt`, `perspective_1.txt`, ...)
8. Repeat for each camera perspective

### 5. Triangulate 3D Positions
```bash
uv run led_solver.py perspective_0.txt perspective_1.txt perspective_2.txt perspective_3.txt perspective_4.txt perspective_5.txt \
    --output led_positions_3d.txt \
    --viz led_positions_3d.html \
    --top 42,17 \
    --bottom 8,99
```

**Tips:**
- Use 6+ perspectives for robust reconstruction
- Provide spatial hints (top/bottom/left/right) if you know some LED positions - helps with orientation
- Check the HTML visualization for obvious errors
- Review rejection statistics to identify problematic cameras or LEDs
- If results are poor, try `--conservative` mode or add more camera angles

### 6. Verify Results
- Open the generated HTML visualization in a browser
- Rotate and inspect the 3D point cloud
- Check that the shape matches your physical installation
- Verify that LED IDs are reasonable and sequential
- Check solver statistics for high rejection rates (may indicate camera or detection issues)

**Note:** You may not achieve 100% calibration of all LEDs. A few "dead pixels" (heavily occluded, hidden, or failed detections) are acceptable. Animation software will set missing LEDs to black.

## LED ID Encoding Scheme

### Ternary Encoding
LEDs identify themselves by flashing a sequence of colors that encode their ID in ternary (base-3):

- **Red** = 0
- **Green** = 1
- **Blue** = 2
- **Least significant digit first** (right-to-left in conventional notation)

### Checksum Validation
To detect transmission errors, LED IDs include a built-in checksum:

1. The raw decoded ternary value must be divisible by 7 (i.e., `value % 7 == 0`)
2. If validation passes, divide by 9 to get the true LED ID: `true_id = value // 9`

### Encoding Example (Python)
```python
def encode_led_id(led_id: int, num_digits: int = 9) -> str:
    """Encode LED ID into ternary color sequence with checksum"""
    # Add checksum: multiply by 9, then add offset to ensure divisible by 7
    n = led_id * 9
    n = n + (7 - (n % 7))

    # Convert to ternary (LSB first)
    colors = []
    for _ in range(num_digits):
        digit = n % 3
        n = n // 3
        colors.append('RGB'[digit])

    return ''.join(colors)

def decode_led_id(color_sequence: str) -> int:
    """Decode ternary color sequence to LED ID, returns -1 if invalid"""
    # Decode ternary (LSB first)
    value = 0
    for i, color in enumerate(color_sequence):
        try:
            digit = 'RGB'.index(color)
        except ValueError:
            return -1  # Invalid color
        value += digit * (3 ** i)

    # Validate checksum
    if value % 7 != 0:
        return -1

    # Extract true ID
    true_id = value // 9
    return true_id

def generate_calibration_pattern(led_id: int, num_digits: int = 9) -> str:
    """Generate looping calibration pattern: M_C_C_..._C_ (M=magenta, _=dark, C=color)"""
    # Encode the LED ID to get color sequence
    color_sequence = encode_led_id(led_id, num_digits)

    # Build the pattern: start with magenta marker
    pattern = ['M', '_']

    # Add each color frame followed by a dark frame
    for color in color_sequence:
        pattern.append(color)
        pattern.append('_')

    # Pattern loops back to magenta marker (no explicit end marker needed)
    return ''.join(pattern)
```

### Example
For LED ID `1` with 9 digits:
- Base value: `1 * 9 = 9`
- Checksum offset: `7 - (9 % 7) = 7 - 2 = 5`
- Final value: `9 + 5 = 14`
- Verify: `14 % 7 = 0` ✓ (valid checksum)
- Decode check: `14 // 9 = 1` ✓ (recovers original ID)
- Ternary representation: `14 = 112` in base 3 (LSB first: 2, 1, 1)
- Color sequence: `BGGRRRRRR` (padded to 9 digits, R=0, G=1, B=2)
- Full calibration pattern: `M_B_G_G_R_R_R_R_R_R_` (20 frames, then loops)
  - Frame 1: Magenta (start marker)
  - Frame 2: Dark
  - Frame 3: Blue (digit 0 = 2)
  - Frame 4: Dark
  - Frame 5: Green (digit 1 = 1)
  - Frame 6: Dark
  - ... (continues for all 9 color frames with dark frames between)
  - Frame 19: Red (digit 8 = 0)
  - Frame 20: Dark
  - (Pattern loops back to frame 1 - next magenta serves as sequence boundary)

## License

MIT License

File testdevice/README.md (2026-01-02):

# LED Test Device

A MicroPython utility for quickly testing single WS2812B LED strings during installation and teardown. Runs on an ESP32-C3 microcontroller with a simple handheld setup, powered by a USB power bank for convenient field testing without external power supplies.

The device uses 4× WS2812B LEDs on a PCB connected directly to the ESP (before the strip) that serve as mode indicators and also act as a "hacky" level-shifter/signal-conditioner for the data stream. The test strip consists of 200 external LEDs (204 total including the indicator LEDs).

## Features

- **Color cycling** - Sequentially displays all colors to test each LED
- **First/last LED blinking** - Validates string completeness and correct length by alternating the first and last LEDs
- **Low brightness operation** - Configured for low power consumption to easily run from a power bank
- **Button-selectable test patterns**:
  - Mode 1: Color cycle with flashing first/last LEDs
  - Mode 2: Minimal blink (first and last LED alternating red)
  - Mode 3: Chase pattern filling the strip
  - Mode 4: Shifting rainbow animation
- **Visual mode indicator** - Built-in LEDs show current mode (1-4 LEDs lit)

## License

MIT License - See source file for full license text

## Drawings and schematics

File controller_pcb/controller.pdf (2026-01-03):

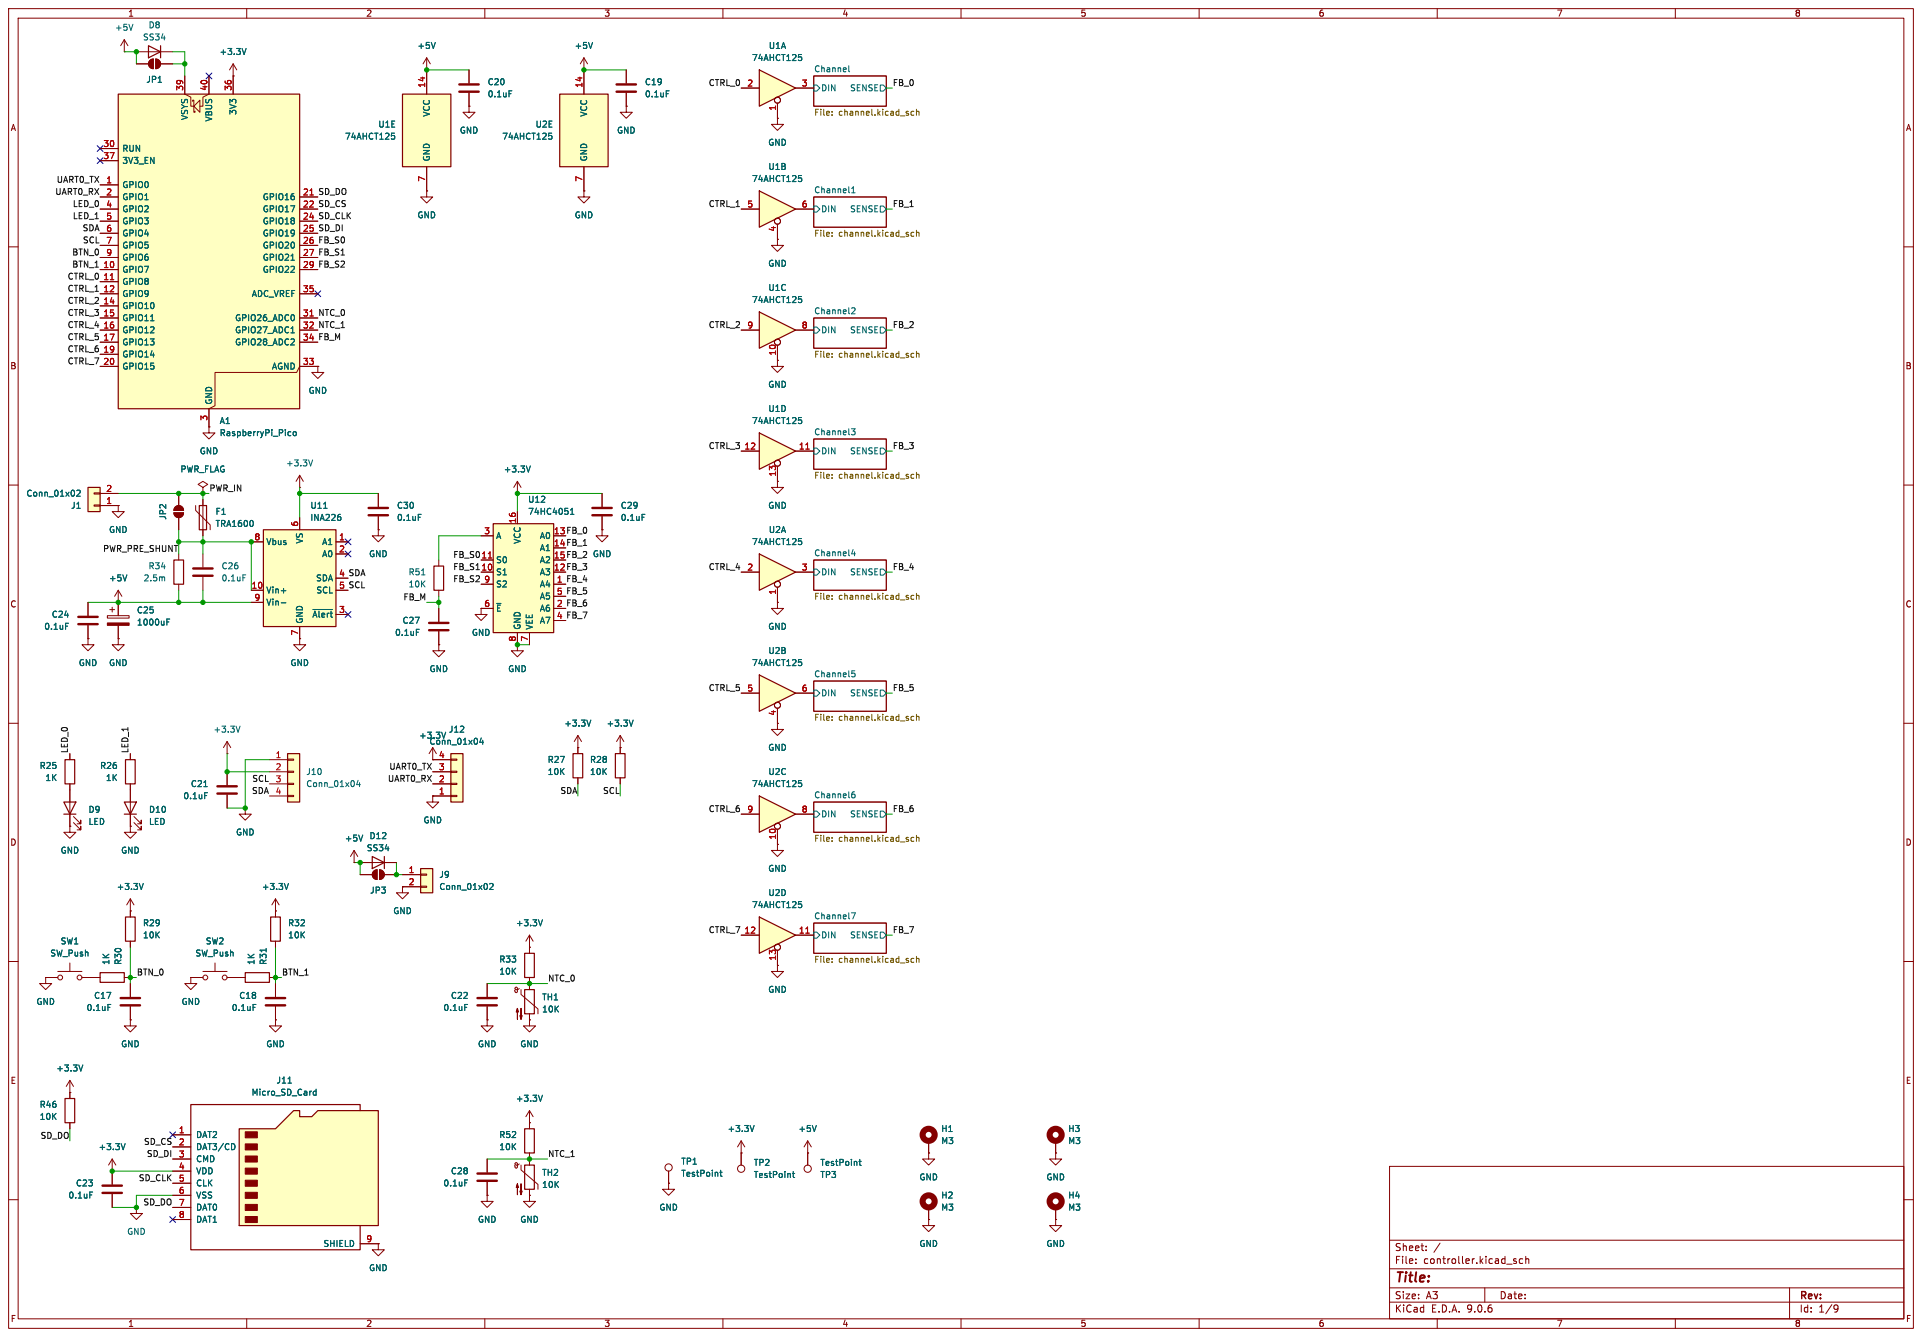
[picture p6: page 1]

Id: 1/9 Title: File: controller.kicad_sch Sheet: /

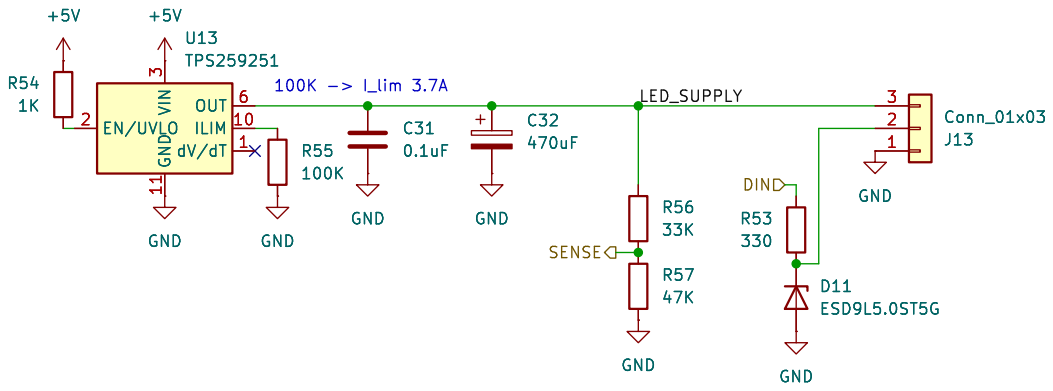
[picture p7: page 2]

Id: 2/9 Title: File: channel.kicad_sch Sheet: /Channel/

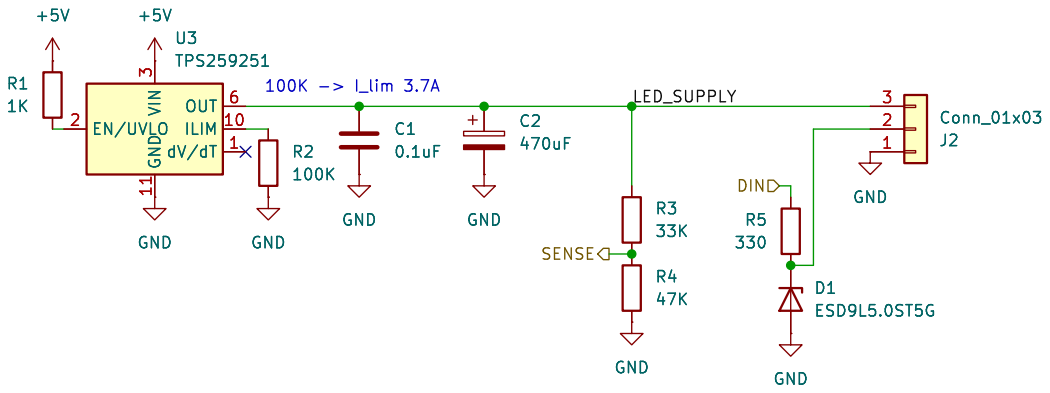
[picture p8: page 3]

Id: 3/9 Title: File: channel.kicad_sch Sheet: /Channel1/

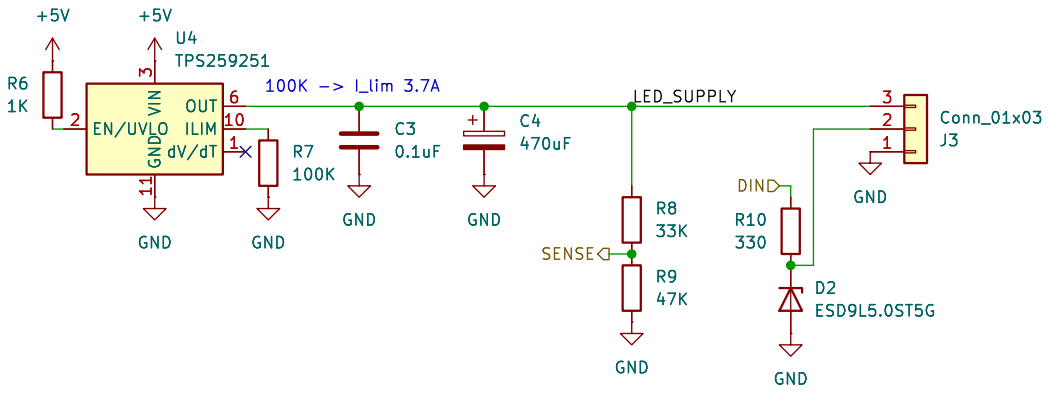
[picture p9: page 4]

Id: 4/9 Title: File: channel.kicad_sch Sheet: /Channel2/ GND

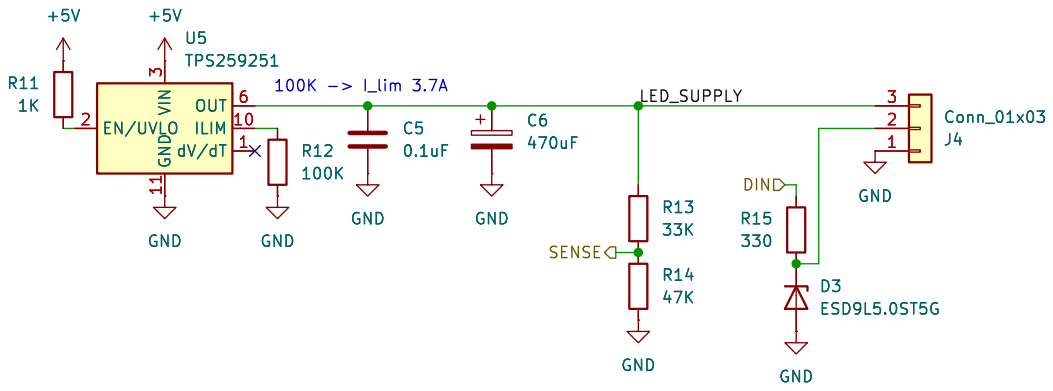
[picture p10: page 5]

Id: 5/9 Title: File: channel.kicad_sch Sheet: /Channel3/

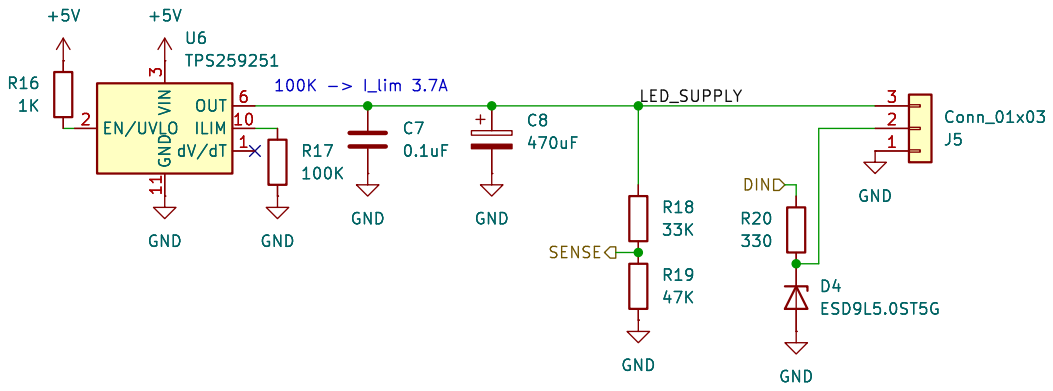
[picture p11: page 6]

Id: 6/9 Title: File: channel.kicad_sch Sheet: /Channel4/

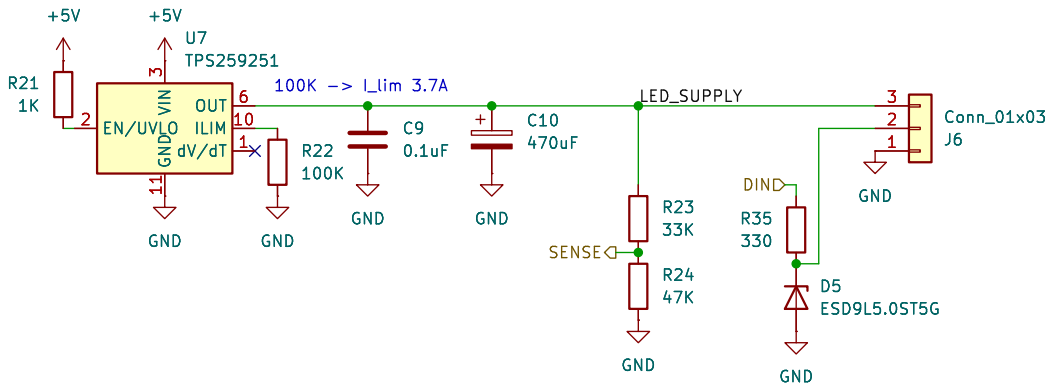
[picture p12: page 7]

Id: 7/9 Title: File: channel.kicad_sch Sheet: /Channel5/

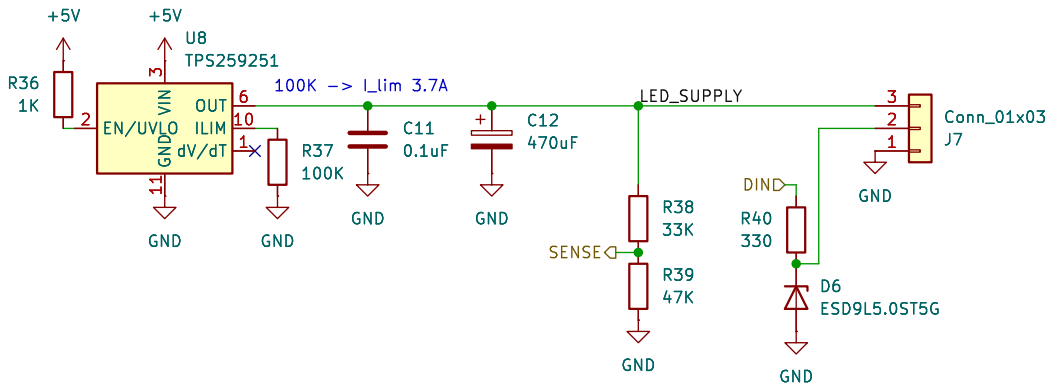
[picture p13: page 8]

Id: 8/9 Title: File: channel.kicad_sch Sheet: /Channel6/ GND

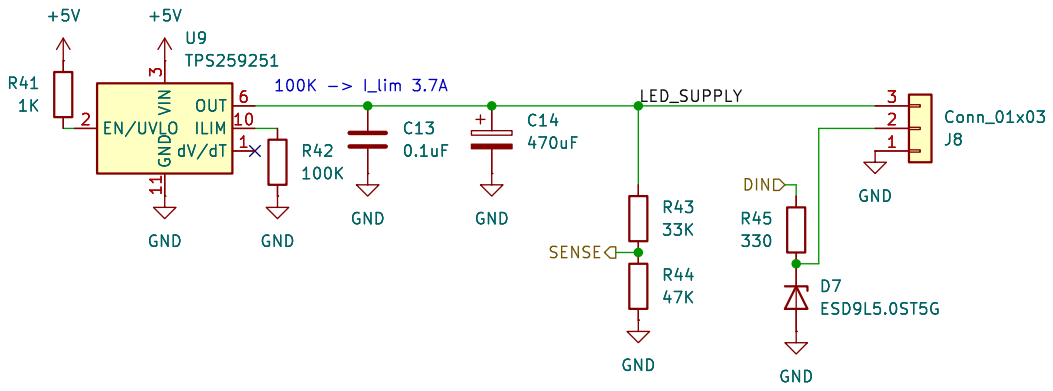
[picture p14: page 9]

Id: 9/9 Title: File: channel.kicad_sch Sheet: /Channel7/

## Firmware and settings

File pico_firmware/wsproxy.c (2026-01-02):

// Copyright (c) 2025 Philip Huppert. Licensed under the MIT License.

/**
 * WS2812 Proxy - UART to WS2812 LED Bridge
 *
 * Receives RGB pixel data via USB UART and forwards to 8 WS2812 channels
 * Supports up to 200 LEDs per channel @ 60Hz refresh rate
 *
 * Protocol Format:
 * 1. Update and auto-flush (immediate update):
 *    [0xFF][CHANNEL_ID][LED_COUNT_LOW][LED_COUNT_HIGH][R][G][B]...[R][G][B]
 *
 * 2. Update buffer only (no flush):
 *    [0xFE][CHANNEL_ID][LED_COUNT_LOW][LED_COUNT_HIGH][R][G][B]...[R][G][B]
 *
 * 3. Selective flush command:
 *    [0xFD][CHANNEL_MASK]
 *
 * 4. Reset Pico:
 *    [0xFC]
 *
 * 5. Start test pattern:
 *    [0xFB][PATTERN_ID]
 *
 * 6. Stop test pattern:
 *    [0xFA]
 *
 * 7. Clear all LEDs:
 *    [0xF9]
 *
 * Command bytes:
 * 0xFF - Update channel and immediately flush to LEDs
 * 0xFE - Update channel buffer only (no flush)
 * 0xFD - Flush command: next byte is channel mask (bit 0=ch0, bit 1=ch1, etc.)
 * 0xFC - Reset Pico
 * 0xFB - Start test pattern (next byte is pattern ID)
 * 0xFA - Stop test pattern
 * 0xF9 - Clear all LEDs (set all channels to black and flush immediately)
 *
 * CHANNEL_ID: 0-7 (which WS2812 channel)
 * LED_COUNT: 16-bit LED count (little-endian)
 * RGB data: 3 bytes per LED (R, G, B)
 * CHANNEL_MASK: 8-bit mask where each bit enables flush for that channel
 * PATTERN_ID: Test pattern number (0-255)
 *
 * Features:
 * - Gamma correction (adjustable)
 * - Current limiting per channel with automatic brightness scaling
 * - Test patterns (auto-activates after timeout)
 * - Periodic status reports (1 Hz)
 * - Temperature monitoring (2x NTC sensors)
 * - Current/voltage monitoring (INA226)
 * - Channel trip detection (8 voltage feedback channels)
 * - Status LEDs (activity and fault indicators)
 * - Button support (reset and pattern cycle)
 */

#include <stdio.h>
#include <stdarg.h>
#include <string.h>
#include <math.h>
#include "pico/stdlib.h"
#include "hardware/pio.h"
#include "hardware/uart.h"
#include "hardware/adc.h"
#include "hardware/i2c.h"
#include "hardware/watchdog.h"
#include "hardware/dma.h"
#include "WS2812.pio.h"

// ============================================================================
// Configuration
// ============================================================================

// WS2812 Configuration
#define NUM_CHANNELS 8
#define MAX_LEDS_PER_CHANNEL 200
#define BYTES_PER_LED 3
#define WS2812_PIN_BASE 8  // GPIO 8-15

// Gamma Correction
#ifndef GAMMA_CORRECTION_ENABLE
#define GAMMA_CORRECTION_ENABLE 1
#endif

#ifndef GAMMA_VALUE
#define GAMMA_VALUE 2.8f
#endif

// Current Limiting Configuration
#define CURRENT_LIMIT_ENABLE 1
#define CURRENT_LIMIT_THRESHOLD 30000  // Brightness units (tunable)

// Test Pattern Configuration
#define TEST_PATTERN_TIMEOUT_MS 5000  // Auto-activate after 5s no data
#define TEST_PATTERN_DEFAULT_LEDS 200 // Default LEDs per channel for patterns
#define NUM_TEST_PATTERNS 6           // Total number of test patterns

// Test Pattern IDs
typedef enum {
    PATTERN_CHANNEL_ID = 0,         // Channel identification with minimal power (first/last N LEDs blink)
    PATTERN_RGB_CYCLE = 1,          // Cycle through Red, Green, Blue
    PATTERN_COLOR_CYCLE = 2,        // Cycle through R, G, B, C, M, Y, W, Black
    PATTERN_END_BLINK = 3,          // Alternating red blink on first and last LED
    PATTERN_TERNARY = 4,            // Ternary encoding for camera calibration
    PATTERN_COLORFUL_TWINKLE = 5    // Channel colors with full twinkling effect
} test_pattern_id_t;

// Update Rates
#define STATUS_REPORT_INTERVAL_MS 1000  // Log status once a second
#define SENSOR_UPDATE_RATE_HZ 20        // Sensor readings at 20 Hz
#define SENSOR_UPDATE_INTERVAL_US (1000000 / SENSOR_UPDATE_RATE_HZ)
#define PATTERN_UPDATE_RATE_HZ 30       // Test pattern animation at 30 Hz
#define PATTERN_UPDATE_INTERVAL_US (1000000 / PATTERN_UPDATE_RATE_HZ)

// Fault Detection Thresholds
#define FAULT_TEMP_THRESHOLD 60.0f      // °C - trigger fault above this temperature
#define FAULT_CURRENT_THRESHOLD 10.0f   // A - trigger fault above this current
#define FAULT_VOLTAGE_THRESHOLD 1.0f    // V - channel active above this voltage (trip below)
#define FAULT_DEBUG_INTERVAL_MS 5000    // Debug: print voltages every 5 seconds

// Debug Configuration
#define DEBUG_ENABLE 0                  // Enable debug output (0=disabled, 1=enabled)

// Sensor Pinout
#define ADC_NTC0 26
#define ADC_NTC1 27
#define ADC_FB_M 28
#define GPIO_FB_S0 20
#define GPIO_FB_S1 21
#define GPIO_FB_S2 22

#define I2C_PORT i2c0
#define I2C_SDA 4
#define I2C_SCL 5
#define I2C_FREQ 400000

// INA226 Configuration
#define INA226_ADDR 0x40
#define INA226_REG_CONFIG 0x00
#define INA226_REG_SHUNT_V 0x01
#define INA226_REG_BUS_V 0x02
#define INA226_REG_CURRENT 0x04
#define INA226_REG_CALIBRATION 0x05

// NTC Configuration
#define NTC_SERIES_R 10000.0f
#define NTC_NOMINAL_R 10000.0f
#define NTC_NOMINAL_T 25.0f
#define NTC_BETA 3950.0f
#define ADC_VREF 3.3f
#define ADC_MAX 4095.0f

// LED Configuration
#define GPIO_LED0 2  // Primary status LED (green)
#define GPIO_LED1 3  // Secondary status LED (fault indicator, red)

// Button Configuration (hardware debounced with caps)
#define GPIO_BUTTON0 6  // Primary button (reset)
#define GPIO_BUTTON1 7  // Secondary button (cycle patterns)

// Protocol Commands
#define CMD_UPDATE_AND_FLUSH 0xFF
#define CMD_UPDATE_ONLY 0xFE
#define CMD_FLUSH 0xFD
#define CMD_RESET 0xFC
#define CMD_START_PATTERN 0xFB
#define CMD_STOP_PATTERN 0xFA
#define CMD_CLEAR_ALL 0xF9

// Color Constants (R, G, B)
#define COLOR_RED       255, 0, 0
#define COLOR_GREEN     0, 255, 0
#define COLOR_BLUE      0, 0, 255
#define COLOR_CYAN      0, 255, 255
#define COLOR_MAGENTA   255, 0, 255
#define COLOR_YELLOW    255, 255, 0
#define COLOR_WHITE     255, 255, 255
#define COLOR_BLACK     0, 0, 0
#define COLOR_LIGHT_RED 255, 128, 128
#define COLOR_LIGHT_BLUE 128, 128, 255

// ============================================================================
// Debug Helper
// ============================================================================

static inline void debug_printf(const char *format, ...) {
#if DEBUG_ENABLE
    va_list args;
    va_start(args, format);
    vprintf(format, args);
    va_end(args);
#else
    (void)format;  // Suppress unused parameter warning
#endif
}

// ============================================================================
// Data Structures
// ============================================================================

// Channel state
typedef struct {
    PIO pio;
    uint sm;
    uint pin;

    // Double buffering for DMA
    uint32_t buffer_a[MAX_LEDS_PER_CHANNEL];
    uint32_t buffer_b[MAX_LEDS_PER_CHANNEL];
    uint32_t *active_buffer;   // Buffer being written to by USB/parser
    uint32_t *output_buffer;   // Buffer being read by DMA

    int dma_channel;
    bool dma_in_progress;

    uint16_t led_count;
    uint32_t current_limit_events;
    bool tripped;
    uint32_t trip_count;
} ws2812_channel_t;

// Parser state
typedef enum {
    STATE_WAIT_COMMAND,
    STATE_READ_CHANNEL,
    STATE_READ_COUNT_LOW,
    STATE_READ_COUNT_HIGH,
    STATE_READ_RGB_DATA,
    STATE_READ_FLUSH_MASK,
    STATE_READ_PATTERN_ID
} parser_state_t;

// Parser context
typedef struct {
    parser_state_t state;
    uint8_t current_command;
    uint8_t current_channel;
    uint16_t current_led_count;
    uint16_t current_led_index;
    uint8_t rgb_byte_index;
    uint8_t current_r, current_g, current_b;
    bool auto_flush;
} parser_context_t;

// Sensor data
typedef struct {
    float temp0;
    float temp1;
    float voltage;
    float current;
    uint8_t fb_mask;
    float fb_voltages[NUM_CHANNELS];
    bool ina226_present;
} sensor_data_t;

// Statistics
typedef struct {
    uint32_t commands;
    uint32_t pixels;
    uint32_t flushes;
    uint32_t errors;
} statistics_t;

// System mode
typedef enum {
    MODE_NORMAL,
    MODE_TEST_PATTERN
} system_mode_t;

// ============================================================================
// Global Variables
// ============================================================================

static ws2812_channel_t channels[NUM_CHANNELS];
static uint8_t gamma_lut[256];

#define UART_BUFFER_SIZE 5120
static uint8_t uart_rx_buffer[UART_BUFFER_SIZE];
static volatile uint16_t uart_rx_count = 0;

// Parser state (grouped into struct)
static parser_context_t parser = {
    .state = STATE_WAIT_COMMAND,
    .current_command = 0,
    .current_channel = 0,
    .current_led_count = 0,
    .current_led_index = 0,
    .rgb_byte_index = 0,
    .current_r = 0,
    .current_g = 0,
    .current_b = 0,
    .auto_flush = true
};

// System state
static system_mode_t system_mode = MODE_NORMAL;
static uint8_t current_test_pattern = 0;
static absolute_time_t last_serial_data_time;
static absolute_time_t boot_time;
static absolute_time_t pattern_start_time;

// Test pattern animation state - pre-computed sine table for efficiency
#define SINE_TABLE_SIZE 512
static uint16_t sine_table[SINE_TABLE_SIZE];  // One sine cycle, centered at 32768

// Statistics (grouped into struct)
static statistics_t stats = {
    .commands = 0,
    .pixels = 0,
    .flushes = 0,
    .errors = 0
};

// Sensor data (grouped into struct)
static sensor_data_t sensors = {
    .temp0 = 0.0f,
    .temp1 = 0.0f,
    .voltage = 0.0f,
    .current = 0.0f,
    .fb_mask = 0xFF,
    .fb_voltages = {0},
    .ina226_present = false
};

// Fault tracking
static bool fault_present = false;
static bool fault_history = false;

// ============================================================================
// Gamma Correction
// ============================================================================

static void calc_gamma_table(float gamma) {
#if GAMMA_CORRECTION_ENABLE
    gamma_lut[0] = 0;
    for (uint16_t i = 1; i < 256; i++) {
        float normalized = (float)i / 255.0f;
        float corrected = powf(normalized, gamma);
        gamma_lut[i] = (uint8_t)(corrected * 255.0f + 0.5f);
    }
#else
    for (uint16_t i = 0; i < 256; i++) {
        gamma_lut[i] = i;
    }
#endif
}

static inline uint8_t gamma_correct(uint8_t value) {
    return gamma_lut[value];
}

static inline uint32_t rgb_to_grb(uint8_t r, uint8_t g, uint8_t b) {
    r = gamma_correct(r);
    g = gamma_correct(g);
    b = gamma_correct(b);
    // Store pre-shifted for DMA (PIO expects data in bits [31:8])
    return (((uint32_t)(g) << 16) | ((uint32_t)(r) << 8) | (uint32_t)(b)) << 8;
}

// ============================================================================
// Current Limiting
// ============================================================================

static uint32_t calculate_brightness_units(uint32_t grb_pixel_shifted) {
    // Data is pre-shifted by 8, so shift right to extract
    uint32_t grb_pixel = grb_pixel_shifted >> 8;
    uint8_t g = (grb_pixel >> 16) & 0xFF;
    uint8_t r = (grb_pixel >> 8) & 0xFF;
    uint8_t b = grb_pixel & 0xFF;
    return (uint32_t)r + (uint32_t)g + (uint32_t)b;
}

static void apply_current_limiting(uint8_t channel_id) {
#if CURRENT_LIMIT_ENABLE
    ws2812_channel_t *ch = &channels[channel_id];

    if (ch->led_count == 0) return;

    // Calculate total brightness from active buffer
    uint32_t total_brightness = 0;
    for (uint16_t i = 0; i < ch->led_count; i++) {
        total_brightness += calculate_brightness_units(ch->active_buffer[i]);
    }

    // Check if limiting needed
    if (total_brightness > CURRENT_LIMIT_THRESHOLD) {
        float scale = (float)CURRENT_LIMIT_THRESHOLD / (float)total_brightness;

        // Scale all pixels in active buffer (data is pre-shifted)
        for (uint16_t i = 0; i < ch->led_count; i++) {
            uint32_t pixel_shifted = ch->active_buffer[i];
            uint32_t pixel = pixel_shifted >> 8;  // Unshift to extract RGB
            uint8_t g = (pixel >> 16) & 0xFF;
            uint8_t r = (pixel >> 8) & 0xFF;
            uint8_t b = pixel & 0xFF;

            g = (uint8_t)(g * scale);
            r = (uint8_t)(r * scale);
            b = (uint8_t)(b * scale);

            // Store back pre-shifted
            ch->active_buffer[i] = (((uint32_t)g << 16) | ((uint32_t)r << 8) | (uint32_t)b) << 8;
        }

        ch->current_limit_events++;
    }
#endif
}

// ============================================================================
// WS2812 Channel Management
// ============================================================================

static void ws2812_channel_init(uint8_t channel_id) {
    ws2812_channel_t *ch = &channels[channel_id];

    ch->pin = WS2812_PIN_BASE + channel_id;
    ch->led_count = 0;
    ch->current_limit_events = 0;
    ch->tripped = false;
    ch->trip_count = 0;

    // Initialize double buffering
    ch->active_buffer = ch->buffer_a;  // Start with buffer A as active
    ch->output_buffer = ch->buffer_b;  // Buffer B will be used for first DMA
    memset(ch->buffer_a, 0, sizeof(ch->buffer_a));
    memset(ch->buffer_b, 0, sizeof(ch->buffer_b));

    // Allocate DMA channel
    ch->dma_channel = dma_claim_unused_channel(true);
    ch->dma_in_progress = false;

    // Distribute channels across both PIO blocks (4 per PIO)
    if (channel_id < 4) {
        ch->pio = pio0;
        ch->sm = channel_id;
    } else {
        ch->pio = pio1;
        ch->sm = channel_id - 4;
    }

    // Load program if not already loaded
    static bool pio0_loaded = false;
    static bool pio1_loaded = false;
    static uint pio0_offset = 0;
    static uint pio1_offset = 0;

    if (ch->pio == pio0 && !pio0_loaded) {
        pio0_offset = pio_add_program(pio0, &ws2812_program);
        pio0_loaded = true;
    } else if (ch->pio == pio1 && !pio1_loaded) {
        pio1_offset = pio_add_program(pio1, &ws2812_program);
        pio1_loaded = true;
    }

    uint offset = (ch->pio == pio0) ? pio0_offset : pio1_offset;

    // Initialize the PIO program for this channel
    ws2812_program_init(ch->pio, ch->sm, offset, ch->pin, 800000, false);

    // Configure DMA channel
    dma_channel_config dma_cfg = dma_channel_get_default_config(ch->dma_channel);
    channel_config_set_transfer_data_size(&dma_cfg, DMA_SIZE_32);   // 32-bit transfers
    channel_config_set_read_increment(&dma_cfg, true);              // Increment read address
    channel_config_set_write_increment(&dma_cfg, false);            // Fixed write (PIO FIFO)
    channel_config_set_dreq(&dma_cfg, pio_get_dreq(ch->pio, ch->sm, true));  // PIO TX DREQ

    // Configure DMA (will be started later with actual buffer)
    dma_channel_configure(
        ch->dma_channel,
        &dma_cfg,
        &ch->pio->txf[ch->sm],   // Write to PIO TX FIFO
        NULL,                    // Read from buffer (set on each transfer)
        0,                       // Transfer count (set on each transfer)
        false                    // Don't start yet
    );
}

static void ws2812_channel_update(uint8_t channel_id) {
    ws2812_channel_t *ch = &channels[channel_id];

    if (ch->led_count == 0) return;

    // Wait for any in-progress DMA to complete
    if (ch->dma_in_progress) {
        dma_channel_wait_for_finish_blocking(ch->dma_channel);
        ch->dma_in_progress = false;
    }

    // Swap buffers: active becomes output, output becomes active
    uint32_t *temp = ch->active_buffer;
    ch->active_buffer = ch->output_buffer;
    ch->output_buffer = temp;

    // Start DMA transfer from output buffer (which has the data we just finished writing)
    // Note: Data is pre-shifted, so we can DMA directly to PIO FIFO
    dma_channel_transfer_from_buffer_now(
        ch->dma_channel,
        ch->output_buffer,
        ch->led_count
    );

    ch->dma_in_progress = true;

    // TODO: clear/zero the active buffer
    stats.flushes++;
}

static void flush_channels(uint8_t channel_mask) {
    for (uint8_t i = 0; i < NUM_CHANNELS; i++) {
        if (channel_mask & (1 << i)) {
            ws2812_channel_update(i);
        }
    }
}

// ============================================================================
// Sensor Reading Functions
// ============================================================================

static bool ina226_write_reg(uint8_t reg, uint16_t value) {
    uint8_t buf[3] = {reg, (value >> 8) & 0xFF, value & 0xFF};
    return i2c_write_blocking(I2C_PORT, INA226_ADDR, buf, 3, false) == 3;
}

static bool ina226_read_reg(uint8_t reg, uint16_t *value) {
    uint8_t buf[2];
    if (i2c_write_blocking(I2C_PORT, INA226_ADDR, &reg, 1, true) != 1) return false;
    if (i2c_read_blocking(I2C_PORT, INA226_ADDR, buf, 2, false) != 2) return false;
    *value = (buf[0] << 8) | buf[1];
    return true;
}

static bool ina226_init(void) {
    // Reset device
    if (!ina226_write_reg(INA226_REG_CONFIG, 0x8000)) return false;
    sleep_ms(10);

    // Configure: continuous mode
    uint16_t config = 0x4127;  // AVG=1, VBUSCT=1.1ms, VSHCT=1.1ms, continuous
    if (!ina226_write_reg(INA226_REG_CONFIG, config)) return false;

    // Set calibration (16A max, 2.5mOhm shunt)
    if (!ina226_write_reg(INA226_REG_CALIBRATION, 4194)) return false;

    return true;
}

static float ina226_read_bus_voltage(void) {
    uint16_t raw;
    if (!ina226_read_reg(INA226_REG_BUS_V, &raw)) return -999.0f;
    return (raw * 1.25f) / 1000.0f;  // Convert to V
}

static float ina226_read_current(void) {
    uint16_t raw;
    if (!ina226_read_reg(INA226_REG_CURRENT, &raw)) return -999.0f;
    int16_t signed_val = (int16_t)raw;
    return (signed_val * 0.48828f) / 1000.0f;  // Convert to A
}

static float adc_to_voltage(uint16_t adc_val) {
    return (adc_val * ADC_VREF) / ADC_MAX;
}

static float ntc_to_temperature(float v_ntc) {
    if (v_ntc >= ADC_VREF) return -999.0f;
    float r_ntc = (v_ntc * NTC_SERIES_R) / (ADC_VREF - v_ntc);
    float t_kelvin = 1.0f / ((1.0f / (NTC_NOMINAL_T + 273.15f)) +
                             (1.0f / NTC_BETA) * logf(r_ntc / NTC_NOMINAL_R));
    return t_kelvin - 273.15f;
}

static float read_ntc_temperature(uint8_t ntc_num) {
    adc_select_input(ntc_num);

    // Take multiple samples and average for noise reduction
    uint32_t adc_sum = 0;
    const uint8_t num_samples = 8;

    for (uint8_t i = 0; i < num_samples; i++) {
        adc_sum += adc_read();
    }

    uint16_t adc_avg = adc_sum / num_samples;
    float voltage = adc_to_voltage(adc_avg);
    return ntc_to_temperature(voltage);
}

static void set_mux_channel(uint8_t channel) {
    gpio_put(GPIO_FB_S0, channel & 0x01);
    gpio_put(GPIO_FB_S1, (channel >> 1) & 0x01);
    gpio_put(GPIO_FB_S2, (channel >> 2) & 0x01);
    // No sleep - let it settle naturally between main loop iterations
}
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
int main() {
    // Initialize stdio (USB serial)
    stdio_init_all();
    sleep_ms(2000);

    boot_time = get_absolute_time();
    last_serial_data_time = boot_time;

    printf("\n=== WS2812 Proxy (Refactored) ===\n");
    printf("Version: 2.0\n");
    printf("Features: Gamma, Current Limiting, Test Patterns, Sensors, Status LEDs, Buttons\n");
    printf("Channels: %d (GPIO %d-%d)\n", NUM_CHANNELS, WS2812_PIN_BASE, WS2812_PIN_BASE + NUM_CHANNELS - 1);
    printf("Max LEDs/channel: %d\n", MAX_LEDS_PER_CHANNEL);

    // Initialize gamma correction
    printf("Gamma correction: ");
#if GAMMA_CORRECTION_ENABLE
    printf("ENABLED (gamma=%.2f)\n", GAMMA_VALUE);
#else
    printf("DISABLED\n");
#endif
    calc_gamma_table(GAMMA_VALUE);

    // Initialize sine table for test patterns
    printf("Initializing test pattern sine table...\n");
    init_sine_table();

    // Initialize current limiting
    printf("Current limiting: ");
#if CURRENT_LIMIT_ENABLE
    printf("ENABLED (threshold=%d)\n", CURRENT_LIMIT_THRESHOLD);
#else
    printf("DISABLED\n");
#endif

    // Initialize WS2812 channels
    printf("Initializing WS2812 channels...\n");
    for (uint8_t i = 0; i < NUM_CHANNELS; i++) {
        ws2812_channel_init(i);
        printf("  Channel %d: GPIO %d (PIO%d, SM%d)\n",
               i, channels[i].pin, pio_get_index(channels[i].pio), channels[i].sm);
    }

    // Initialize sensors
    printf("Initializing sensors...\n");
    init_sensors();
    printf("  INA226: %s\n", sensors.ina226_present ? "OK" : "NOT FOUND");

    // Initialize LEDs and buttons
    init_leds();
    init_buttons();

    printf("\n=== Ready ===\n");
    printf("Commands: 0xFF=Update+Flush, 0xFE=Update, 0xFD=Flush, 0xFC=Reset, 0xFB=Pattern, 0xFA=Stop, 0xF9=ClearAll\n");
    printf("Main loop: runs as fast as possible (sensors: %d Hz, patterns: %d Hz)\n\n",
           SENSOR_UPDATE_RATE_HZ, PATTERN_UPDATE_RATE_HZ);

    // Main loop runs as fast as possible
    // Individual functions handle their own timing requirements
    while (true) {
        // Execute main loop tasks
        parse_uart_data();

        // DMA handles LED updates in background - no blocking needed
        update_test_pattern();
        check_timeout();
        update_sensors();
        print_status_report();
        update_status_leds();
        check_buttons();

        tight_loop_contents();
    }

    return 0;
}

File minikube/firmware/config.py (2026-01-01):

# Hardware Configuration for LED Cube
# Based on testdevice.py configuration adapted for 74-LED cube

# GPIO Configuration
BUTTON_PIN = 9           # Boot button (active low with pull-up)
LED_PIN = 20             # WS2812 data line

# LED Strip Configuration
EXTERNAL_START = 4       # Offset for external cube LEDs in strip (skips built-in LEDs)

# Brightness Configuration
BRIGHTNESS = 255          # Power-saving brightness (0-255)
                        # Low brightness reduces USB power bank load

# Timing Configuration
FRAME_TIME = 33          # Target 30 FPS (33ms per frame)
BUTTON_DEBOUNCE = 50     # 50ms debounce window for button presses

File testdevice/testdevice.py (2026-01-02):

# Copyright (c) 2025 Philip Huppert. Licensed under the MIT License.

"""
MicroPython program for ESP32-C3 LED test device
- Button (boot button) on GPIO 9 (pull-up, active low)
- WS2812 LED string on GPIO 20
- 4 built-in LEDs + 200 external LEDs = 204 total
- Operates from USB power bank with low brightness levels
"""

import machine
import neopixel
import time

# Configuration
BUTTON_PIN = 9
LED_PIN = 20
NUM_LEDS = 204  # 4 built-in + 200 external
BUILTIN_LEDS = 4
EXTERNAL_START = 4
EXTERNAL_END = 203
BRIGHTNESS = 10  # Low brightness to save power (0-255)
FRAME_TIME = 10  # ms per frame (100 Hz)

# Initialize hardware
button = machine.Pin(BUTTON_PIN, machine.Pin.IN, machine.Pin.PULL_UP)
np = neopixel.NeoPixel(machine.Pin(LED_PIN), NUM_LEDS)

# Color constants (RGB) at low brightness
def scale_color(r, g, b):
    return (r * BRIGHTNESS // 255, g * BRIGHTNESS // 255, b * BRIGHTNESS // 255)

RED = scale_color(255, 0, 0)
GREEN = scale_color(0, 255, 0)
BLUE = scale_color(0, 0, 255)
CYAN = scale_color(0, 255, 255)
MAGENTA = scale_color(255, 0, 255)
YELLOW = scale_color(255, 255, 0)
WHITE = scale_color(255, 255, 255)
BLACK = (0, 0, 0)

COLOR_SEQUENCE_SHORT = [RED, GREEN, BLUE]
COLOR_SEQUENCE_BW = [RED, GREEN, BLUE, CYAN, MAGENTA, YELLOW, WHITE, BLACK]
COLOR_SEQUENCE_LONG = [RED, GREEN, BLUE, CYAN, MAGENTA, YELLOW]

# HSV to RGB conversion
def hsv_to_rgb(h, s, v):
    """Convert HSV to RGB. h: 0-1, s: 0-1, v: 0-1. Returns (r, g, b) scaled by brightness."""
    if s == 0.0:
        rgb = (int(v * 255), int(v * 255), int(v * 255))
    else:
        i = int(h * 6.0)
        f = (h * 6.0) - i
        p = v * (1.0 - s)
        q = v * (1.0 - s * f)
        t = v * (1.0 - s * (1.0 - f))
        i = i % 6
        if i == 0:
            rgb = (v, t, p)
        elif i == 1:
            rgb = (q, v, p)
        elif i == 2:
            rgb = (p, v, t)
        elif i == 3:
            rgb = (p, q, v)
        elif i == 4:
            rgb = (t, p, v)
        else:
            rgb = (v, p, q)
        rgb = (int(rgb[0] * 255), int(rgb[1] * 255), int(rgb[2] * 255))

    # Apply brightness scaling
    return scale_color(rgb[0], rgb[1], rgb[2])

# Mode base class
class Mode:
    def __init__(self, current_time):
        """Initialize mode with current time"""
        pass

    def update(self, current_time):
        """Update LED state - must be implemented by subclasses"""
        raise NotImplementedError

class Mode1(Mode):
    """Mode 1: Cycle colors with first/last LED flashing"""
    def __init__(self, current_time):
        super().__init__(current_time)
        self.color_idx = 0
        self.flash_state = False
        self.last_color_change = current_time
        self.last_flash = current_time

    def update(self, current_time):
        # Color cycle every 250ms
        if time.ticks_diff(current_time, self.last_color_change) >= 500:
            color = COLOR_SEQUENCE_BW[self.color_idx]
            for i in range(EXTERNAL_START, EXTERNAL_END + 1):
                np[i] = color
            self.color_idx = (self.color_idx + 1) % len(COLOR_SEQUENCE_BW)
            self.last_color_change = current_time

        # Flash first and last LED alternating at 125ms
        if time.ticks_diff(current_time, self.last_flash) >= 250:
            if self.flash_state:
                np[EXTERNAL_START] = WHITE
                np[EXTERNAL_END] = BLACK
            else:
                np[EXTERNAL_START] = BLACK
                np[EXTERNAL_END] = WHITE
            self.flash_state = not self.flash_state
            self.last_flash = current_time

class Mode2(Mode):
    """Mode 2: Minimal blink - first and last LED red alternating"""
    def __init__(self, current_time):
        super().__init__(current_time)
        self.flash_state = False
        self.last_flash = current_time

    def update(self, current_time):
        # Flash first and last LED alternating at 125ms
        if time.ticks_diff(current_time, self.last_flash) >= 500:
            if self.flash_state:
                np[EXTERNAL_START] = RED
                np[EXTERNAL_END] = BLACK
            else:
                np[EXTERNAL_START] = BLACK
                np[EXTERNAL_END] = RED
            self.flash_state = not self.flash_state
            self.last_flash = current_time

class Mode3(Mode):
    """Mode 3: Chase - fill strip one LED at a time, cycling through colors"""
    def __init__(self, current_time):
        super().__init__(current_time)
        self.color_idx = 0
        self.led_idx = EXTERNAL_START
        self.last_update = current_time

    def update(self, current_time):
        # Update one LED every 10ms
        if time.ticks_diff(current_time, self.last_update) >= 10:
            color = COLOR_SEQUENCE_LONG[self.color_idx]
            np[self.led_idx] = color
            self.led_idx += 1

            # When we reach the end, start over with next color
            if self.led_idx > EXTERNAL_END:
                self.led_idx = EXTERNAL_START
                self.color_idx = (self.color_idx + 1) % len(COLOR_SEQUENCE_LONG)

            self.last_update = current_time

class Mode4(Mode):
    """Mode 4: Shifting rainbow - hue cycle repeated 3 times across strip"""
    def __init__(self, current_time):
        super().__init__(current_time)
        self.phase_offset = 0.0
        self.last_update = current_time
        self.num_repetitions = 3  # Number of rainbow cycles across the strip

    def update(self, current_time):
        # Update animation every 50ms
        if time.ticks_diff(current_time, self.last_update) >= 50:
            strip_length = EXTERNAL_END - EXTERNAL_START + 1

            for i in range(EXTERNAL_START, EXTERNAL_END + 1):
                led_position = i - EXTERNAL_START
                # Calculate hue based on position and phase offset
                hue = ((led_position / strip_length) * self.num_repetitions + self.phase_offset) % 1.0
                color = hsv_to_rgb(hue, 1.0, 1.0)
                np[i] = color

            # Increment phase to create shifting effect
            self.phase_offset = (self.phase_offset + 0.01) % 1.0
            self.last_update = current_time

def clear_all():
    """Turn off all LEDs"""
    for i in range(NUM_LEDS):
        np[i] = BLACK
    np.write()

def clear_external():
    """Turn off only external LEDs (preserve internal LEDs)"""
    for i in range(EXTERNAL_START, NUM_LEDS):
        np[i] = BLACK

def set_mode_indicator(mode):
    """Set internal LEDs to indicate current mode (1-4 LEDs lit)"""
    for i in range(BUILTIN_LEDS):
        if i < mode:
            np[i] = RED
        else:
            np[i] = BLACK
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

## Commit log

2026-01-01 Add minikube
    [base.3mf, corner.3mf, stick.3mf]
2026-01-02 Import pico firmware
2026-01-03 Update documentation of calibration tools, workflow and algorithms.
2026-01-03 Add PDF export of schematic
2026-01-04 Add LED strings to mechanical spec
2026-06-07 Dodecahedron variant
    [corner_dodecahedron.3mf]
